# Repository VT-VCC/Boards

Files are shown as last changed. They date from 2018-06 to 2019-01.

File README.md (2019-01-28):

# Board Layouts

This repository contains all of the layouts for the custom boards on the CERES cubesat.

- **Motherboard (Rev. C)** - The current main processor board.
- **Communications Board (Rev. A)** - The current combined PINAV GPS and Lithium Radio commications board.
- **GPS Board** and **Radio Board** - These are legacy designs.

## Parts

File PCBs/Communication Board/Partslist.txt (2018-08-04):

Partlist

Exported from Communication Board Rev A.brd at 8/4/18 3:42 PM

EAGLE Version 9.1.2 Copyright (c) 1988-2018 Autodesk, Inc.

Assembly variant: 

Part            Value                             Package               Library         Position (mil)        Orientation

C1              0.1uF                             C0805                 resistor        (1675 1080)           R270
C2              10uF                              C0805                 resistor        (1670 2615)           R90
C3              0.1uF                             C0805                 resistor        (2386.33858 257.12598) R180
C4              1uF                               C0805                 resistor        (2386.33858 165)      R180
GND             TPSQTP10SQ                        TP10SQ                testpad         (2125 125)            R90
GPS_3V3         TPSQTP10SQ                        TP10SQ                testpad         (1975 125)            R90
GPS_PF          TPSQTP10SQ                        TP10SQ                testpad         (1825 125)            R90
GPS_RX          TPSQTP10SQ                        TP10SQ                testpad         (1375 125)            R90
GPS_TX          TPSQTP10SQ                        TP10SQ                testpad         (1525 125)            R90
GPS_VPP         TPSQTP10SQ                        TP10SQ                testpad         (1675 125)            R90
LITHIUM-2       LI-2                              LI-2                  Cubesat         (275 550)             R0
LI_3V3          TPSQTP10SQ                        TP10SQ                testpad         (775 125)             R90
LI_AMP          TPSQTP10SQ                        TP10SQ                testpad         (625 125)             R90
LI_RST          TPSQTP10SQ                        TP10SQ                testpad         (925 125)             R90
LI_RX           TPSQTP10SQ                        TP10SQ                testpad         (1075 125)            R90
LI_TX           TPSQTP10SQ                        TP10SQ                testpad         (1225 125)            R90
OA_RST          TPSQTP10SQ                        TP10SQ                testpad         (475 125)             R90
PINAV-CONNECTOR HLE-110-02-X-DVHLE-110-X-DV-PE-BA HLE-110-02-X-DV-PE-BE HLE-110-02-X-DV (2421.25984 807.08661) R180
R1              47k                               R0805                 resistor        (875 425)             R0
R2              0                                 R0805                 resistor        (1632 3063)           R270
U$1             PC104_NO_DIMENSION                PC104_NO_DIMENSION    Cubesat         (0 0)                 R0

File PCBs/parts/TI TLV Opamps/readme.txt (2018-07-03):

To import your new library into Eagle:
1. Start Eagle.
2. In the control panel window, Select File -> New -> Library from the menu.
3. In the blank library window, select File -> Execute Script from the menu.
5. Browse to your newly exported Eagle Script file (".scr" file extension)
6. After opening the file, the script will populate the new library.
7. Use File -> Save (or Save As..) to save the library to the desired location in Eagle native format.

**************************************************************
**    !!!!!!!!!!!!!        WARNING        !!!!!!!!!!!!!     **
**************************************************************

Besure to check the documentation layer, "48"/"Document", for important information that may seem to be missing or have not translated properly!

For additional information, please visit this site:
http://www.accelerated-designs.com/help/Eagle_import.html

You may also find this video helpful:
http://youtu.be/5jGuWY-Yy3Q

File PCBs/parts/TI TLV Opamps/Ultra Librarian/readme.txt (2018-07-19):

 

**********************************************************
*************  Important Instructions Follow  ************
**********************************************************
 
All files exported to: D:\Export_Storage\ExportBase\1\3783\Output\Eagle\Eagle\Eagle.xml

To import your new library into Eagle:
1. Start Eagle.
2. In the control panel window, Select File -> New -> Library from the menu.
3. In the blank library window, select File -> Execute Script from the menu.
5. Browse to your newly exported Eagle Script file (".scr" file extension)
6. After opening the file, the script will populate the new library.
7. Use File -> Save (or Save As..) to save the library to the desired location in Eagle native format.

**************************************************************
**    !!!!!!!!!!!!!        WARNING        !!!!!!!!!!!!!     **
**************************************************************

Besure to check the documentation layer, "48"/"Document", for important information that may seem to be missing or have not translated properly!

For additional information, please visit this site:
http://www.accelerated-designs.com/help/Eagle_import.html

You may also find this video helpful:
http://youtu.be/5jGuWY-Yy3Q

Ultra Librarian Gold 8.2.225 Process Report

Message - Padstack "RX66Y20D0T" Shape(4) is a CIRCLE with no diameter.
Message - Padstack "RX90Y24D0T" Shape(4) is a CIRCLE with no diameter.
Message - Padstack "RX78Y22D0T" Shape(4) is a CIRCLE with no diameter.

TextStyle count:  24
Padstack count:   3
Pattern count:    3
Symbol count:     1
Component count:  1

Export

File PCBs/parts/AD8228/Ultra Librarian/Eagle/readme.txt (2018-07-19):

 

**********************************************************
*************  Important Instructions Follow  ************
**********************************************************
 
All files exported to: D:\Export_Storage\ExportBase\1\3786\Output\Eagle\Eagle\Eagle.xml

To import your new library into Eagle:
1. Start Eagle.
2. In the control panel window, Select File -> New -> Library from the menu.
3. In the blank library window, select File -> Execute Script from the menu.
5. Browse to your newly exported Eagle Script file (".scr" file extension)
6. After opening the file, the script will populate the new library.
7. Use File -> Save (or Save As..) to save the library to the desired location in Eagle native format.

**************************************************************
**    !!!!!!!!!!!!!        WARNING        !!!!!!!!!!!!!     **
**************************************************************

Besure to check the documentation layer, "48"/"Document", for important information that may seem to be missing or have not translated properly!

For additional information, please visit this site:
http://www.accelerated-designs.com/help/Eagle_import.html

You may also find this video helpful:
http://youtu.be/5jGuWY-Yy3Q

The Symbol AD8228ARZ was missing a RefDes attribute, a refdes was created for the symbol.
The Symbol AD8228ARZ was missing a Type attribute, a type was created for the symbol.
The Symbol AD8228ARZ was missing a Value attribute, a value was created for the symbol.

Ultra Librarian Gold 8.2.225 Process Report

Message - Padstack "RX74Y20D0T" Shape(4) is a CIRCLE with no diameter.
Message - Padstack "RX98Y24D0T" Shape(4) is a CIRCLE with no diameter.
Message - Padstack "RX86Y22D0T" Shape(4) is a CIRCLE with no diameter.

TextStyle count:  24
Padstack count:   3
Pattern count:    3
Symbol count:     1
Component count:  1

Export

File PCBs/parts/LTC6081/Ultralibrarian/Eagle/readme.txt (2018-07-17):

 

**********************************************************
*************  Important Instructions Follow  ************
**********************************************************
 
All files exported to: D:\Export_Storage\ExportBase\1\3724\Output\Eagle\Eagle\Eagle.xml

To import your new library into Eagle:
1. Start Eagle.
2. In the control panel window, Select File -> New -> Library from the menu.
3. In the blank library window, select File -> Execute Script from the menu.
5. Browse to your newly exported Eagle Script file (".scr" file extension)
6. After opening the file, the script will populate the new library.
7. Use File -> Save (or Save As..) to save the library to the desired location in Eagle native format.

**************************************************************
**    !!!!!!!!!!!!!        WARNING        !!!!!!!!!!!!!     **
**************************************************************

Besure to check the documentation layer, "48"/"Document", for important information that may seem to be missing or have not translated properly!

For additional information, please visit this site:
http://www.accelerated-designs.com/help/Eagle_import.html

You may also find this video helpful:
http://youtu.be/5jGuWY-Yy3Q

Symbol "LTC6081HMS8#PBF" renamed to "LTC6081HMS8PBF"
Component "LTC6081HMS8#PBF" renamed to "LTC6081HMS8PBF"

Ultra Librarian Gold 8.2.225 Process Report

Message - Padstack "RX43Y15D0T" Shape(4) is a CIRCLE with no diameter.
Message - Padstack "RX67Y19D0T" Shape(4) is a CIRCLE with no diameter.
Message - Padstack "RX55Y17D0T" Shape(4) is a CIRCLE with no diameter.

TextStyle count:  24
Padstack count:   3
Pattern count:    3
Symbol count:     1
Component count:  1

Export

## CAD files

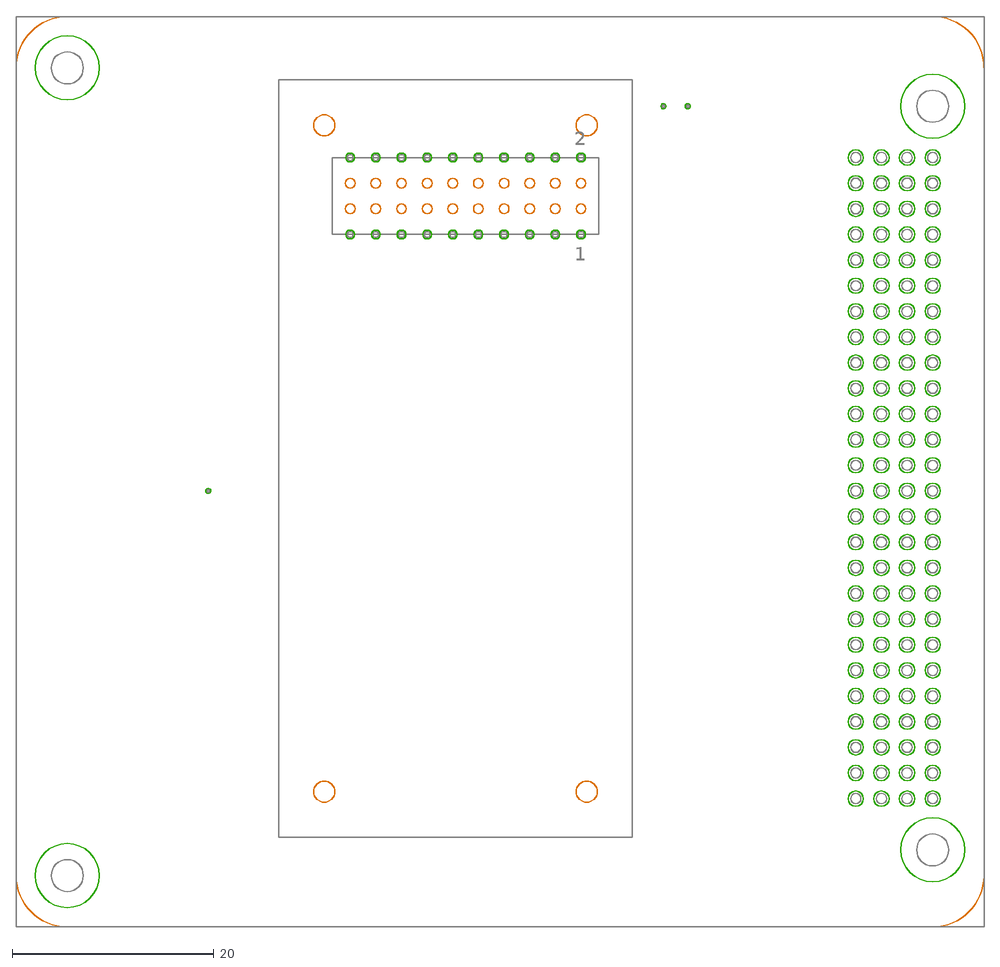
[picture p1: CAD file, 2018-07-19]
PCBs/GPS Board/GPS Board Rev C.dxf
2
1

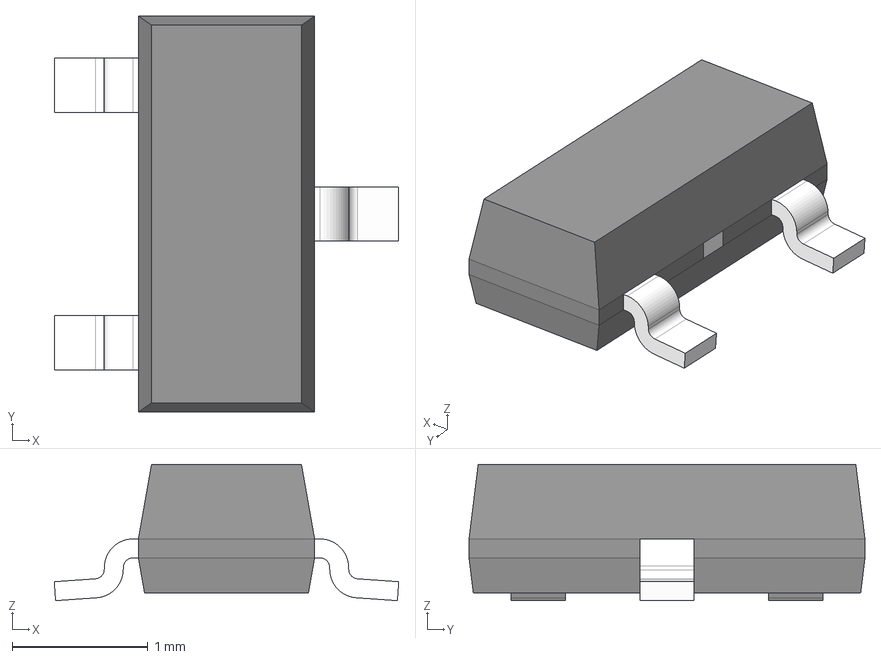
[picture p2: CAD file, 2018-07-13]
PCBs/parts/REF3330/DBZ0003A.stp
2.54 x 2.92 x 1.01 mm
BODY-SOT
LEAD-SOT x 3
PIN1-ID
TIEBAR

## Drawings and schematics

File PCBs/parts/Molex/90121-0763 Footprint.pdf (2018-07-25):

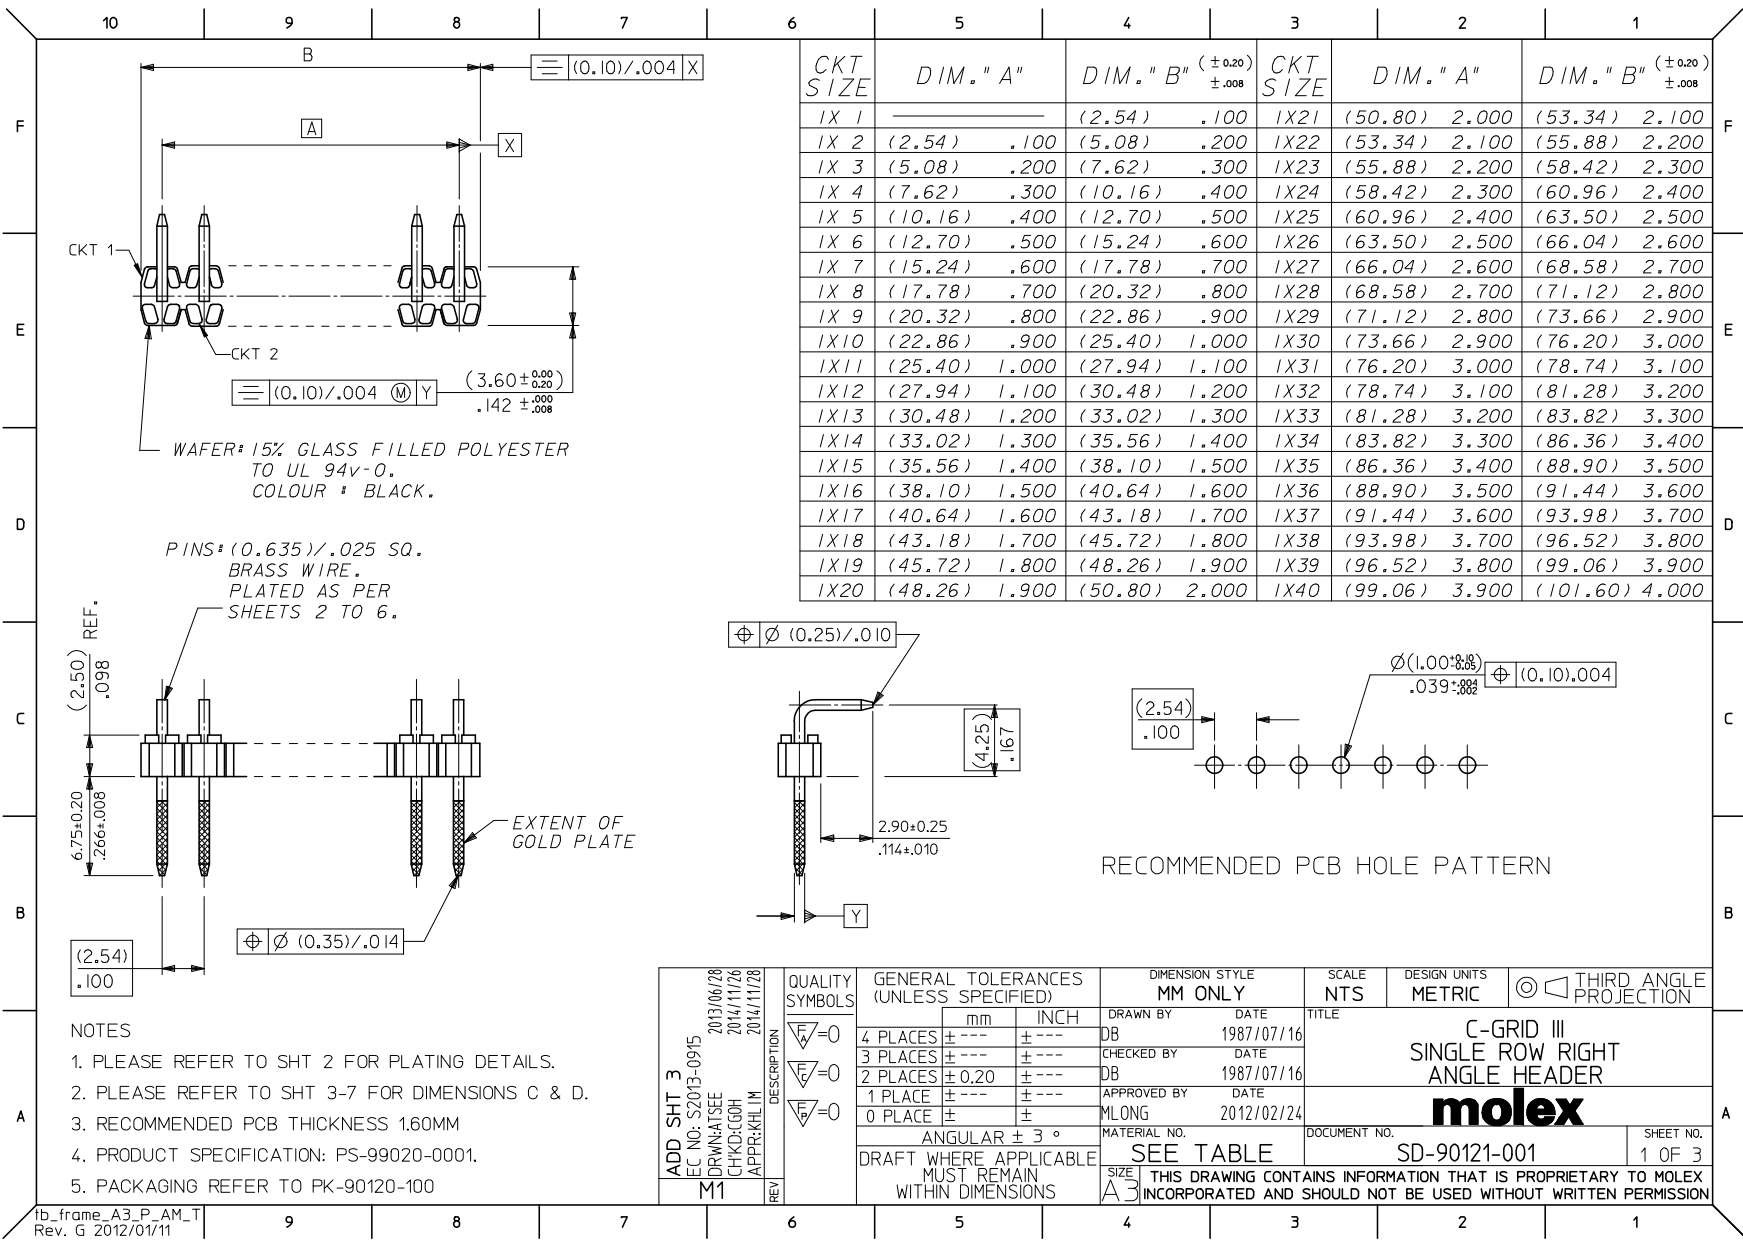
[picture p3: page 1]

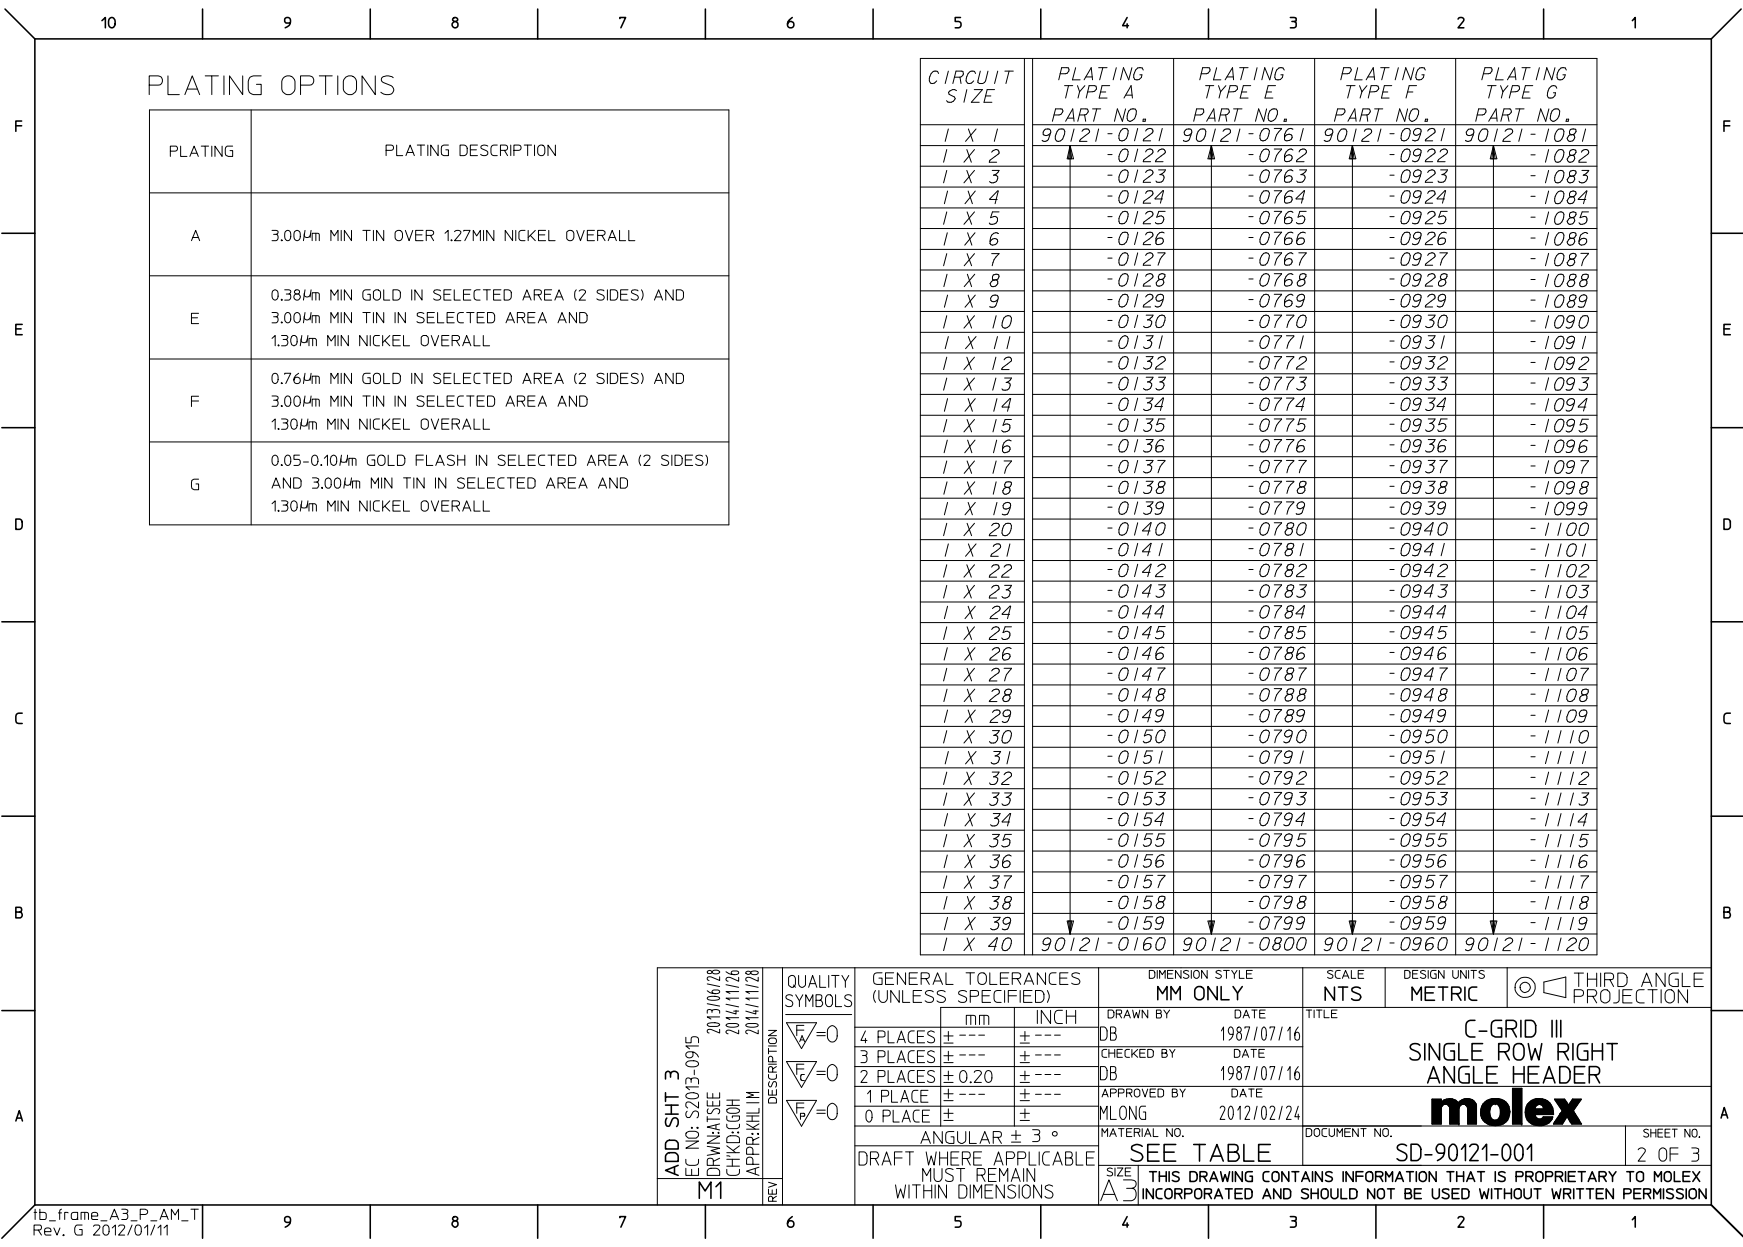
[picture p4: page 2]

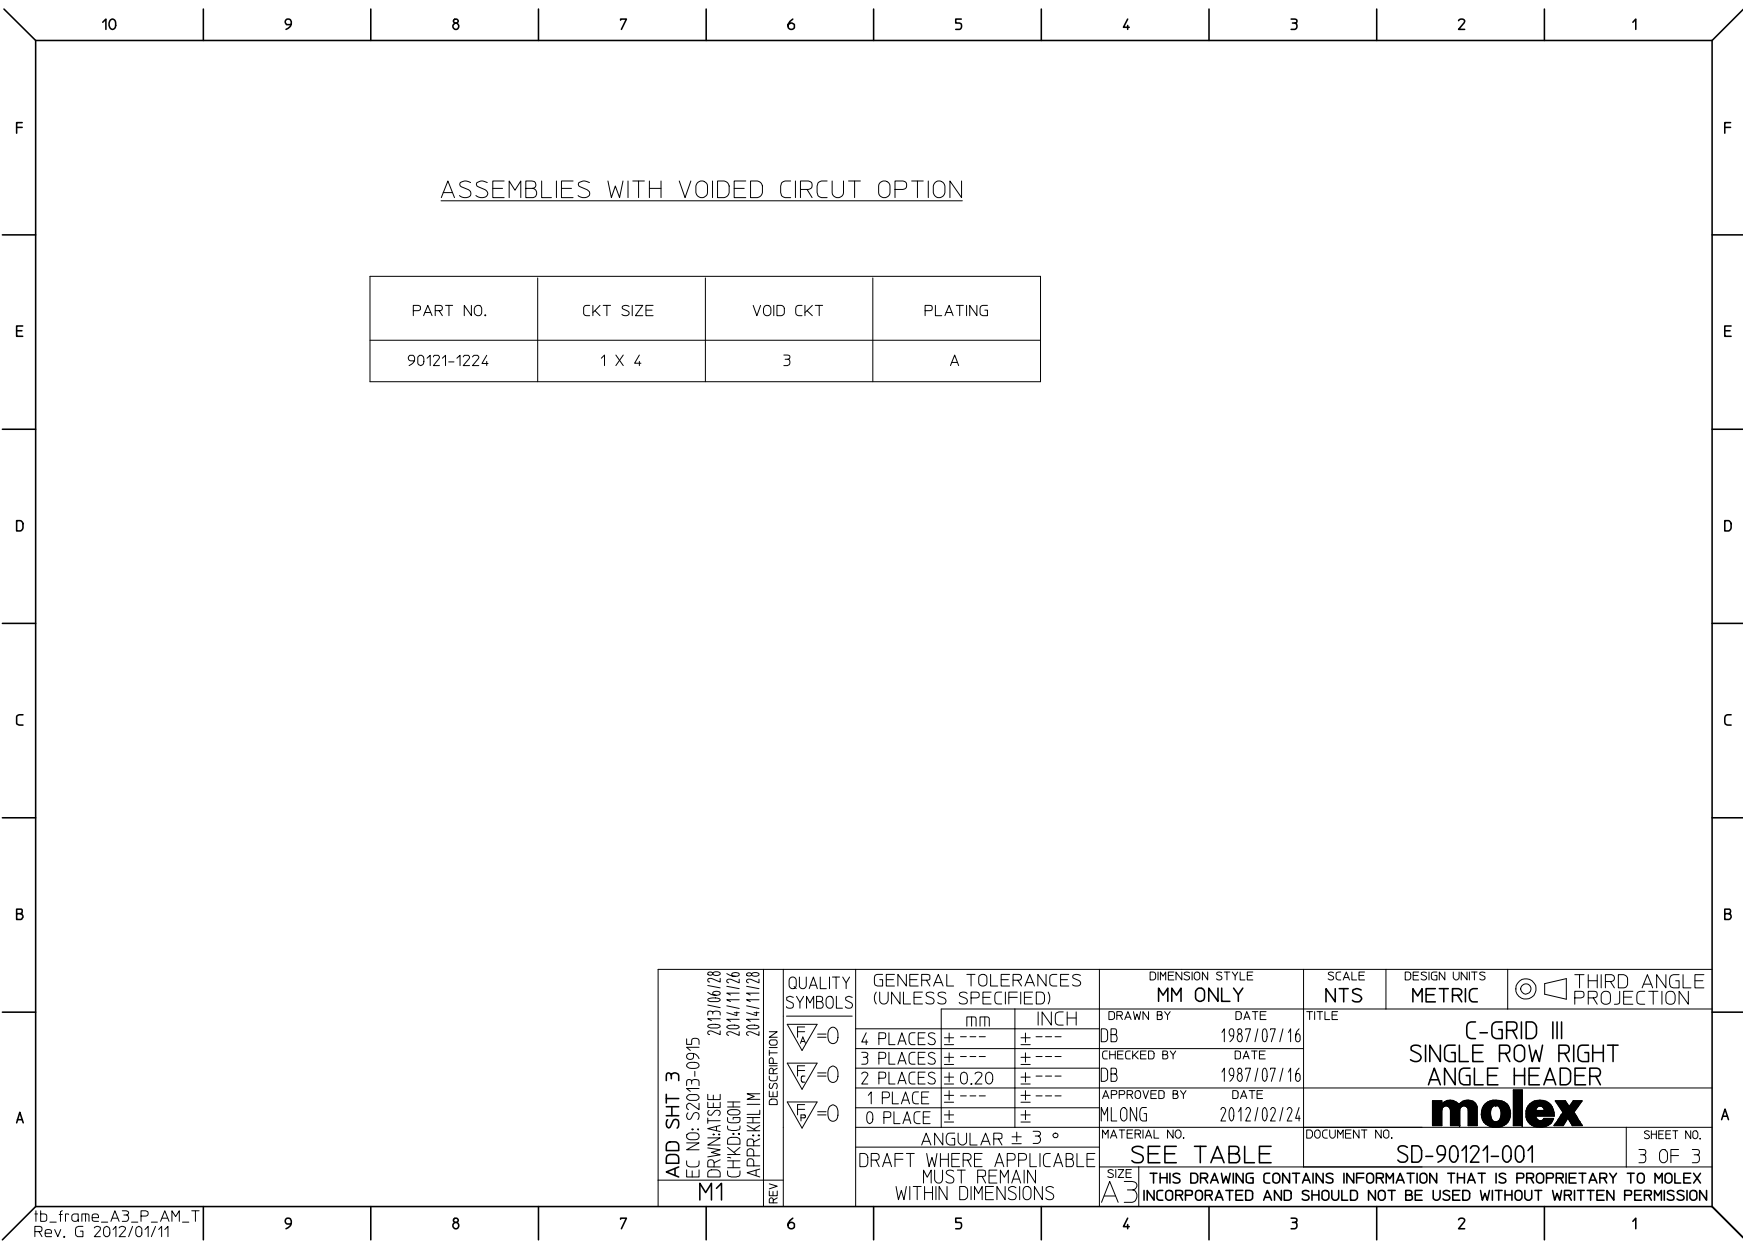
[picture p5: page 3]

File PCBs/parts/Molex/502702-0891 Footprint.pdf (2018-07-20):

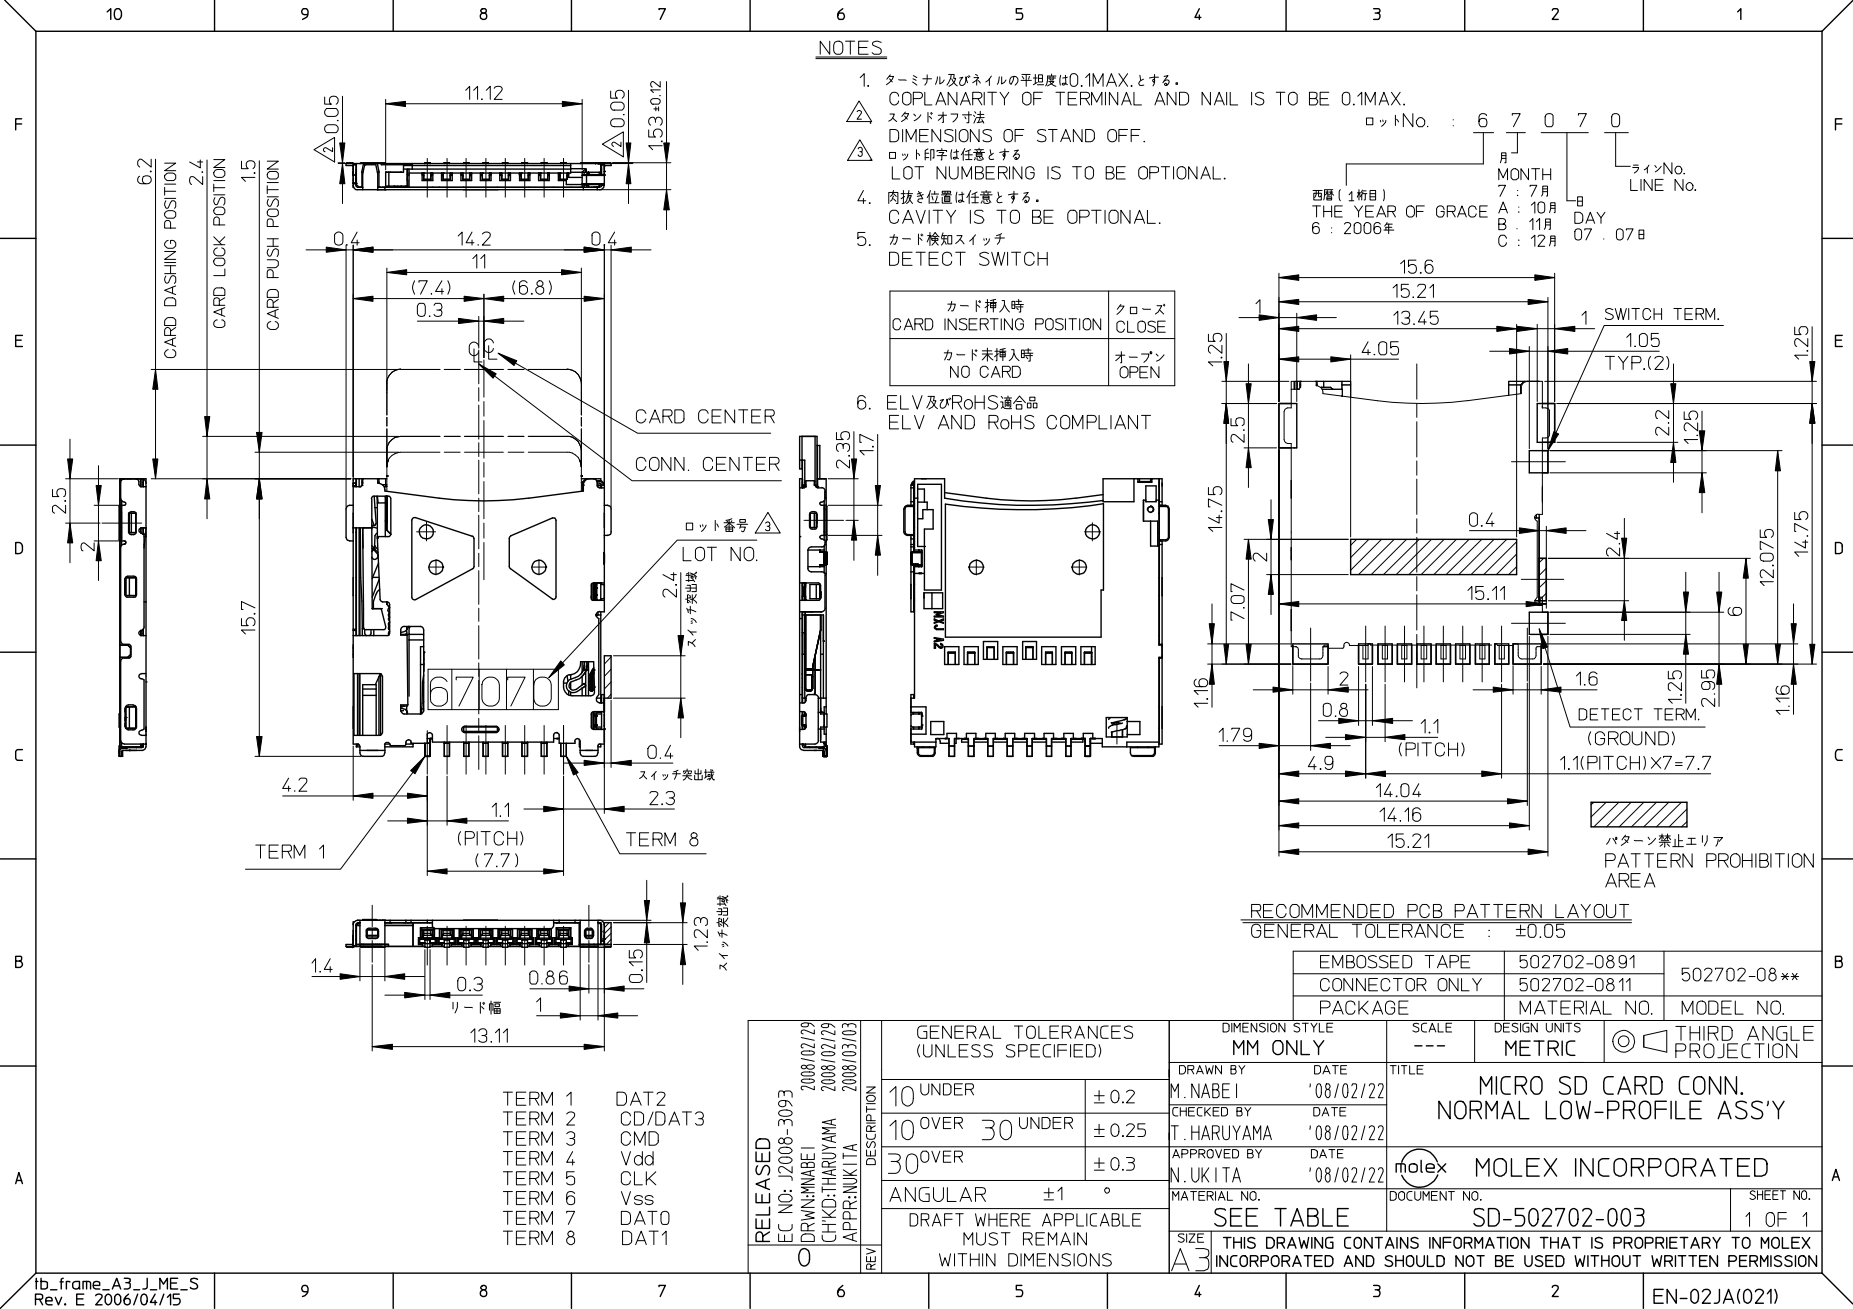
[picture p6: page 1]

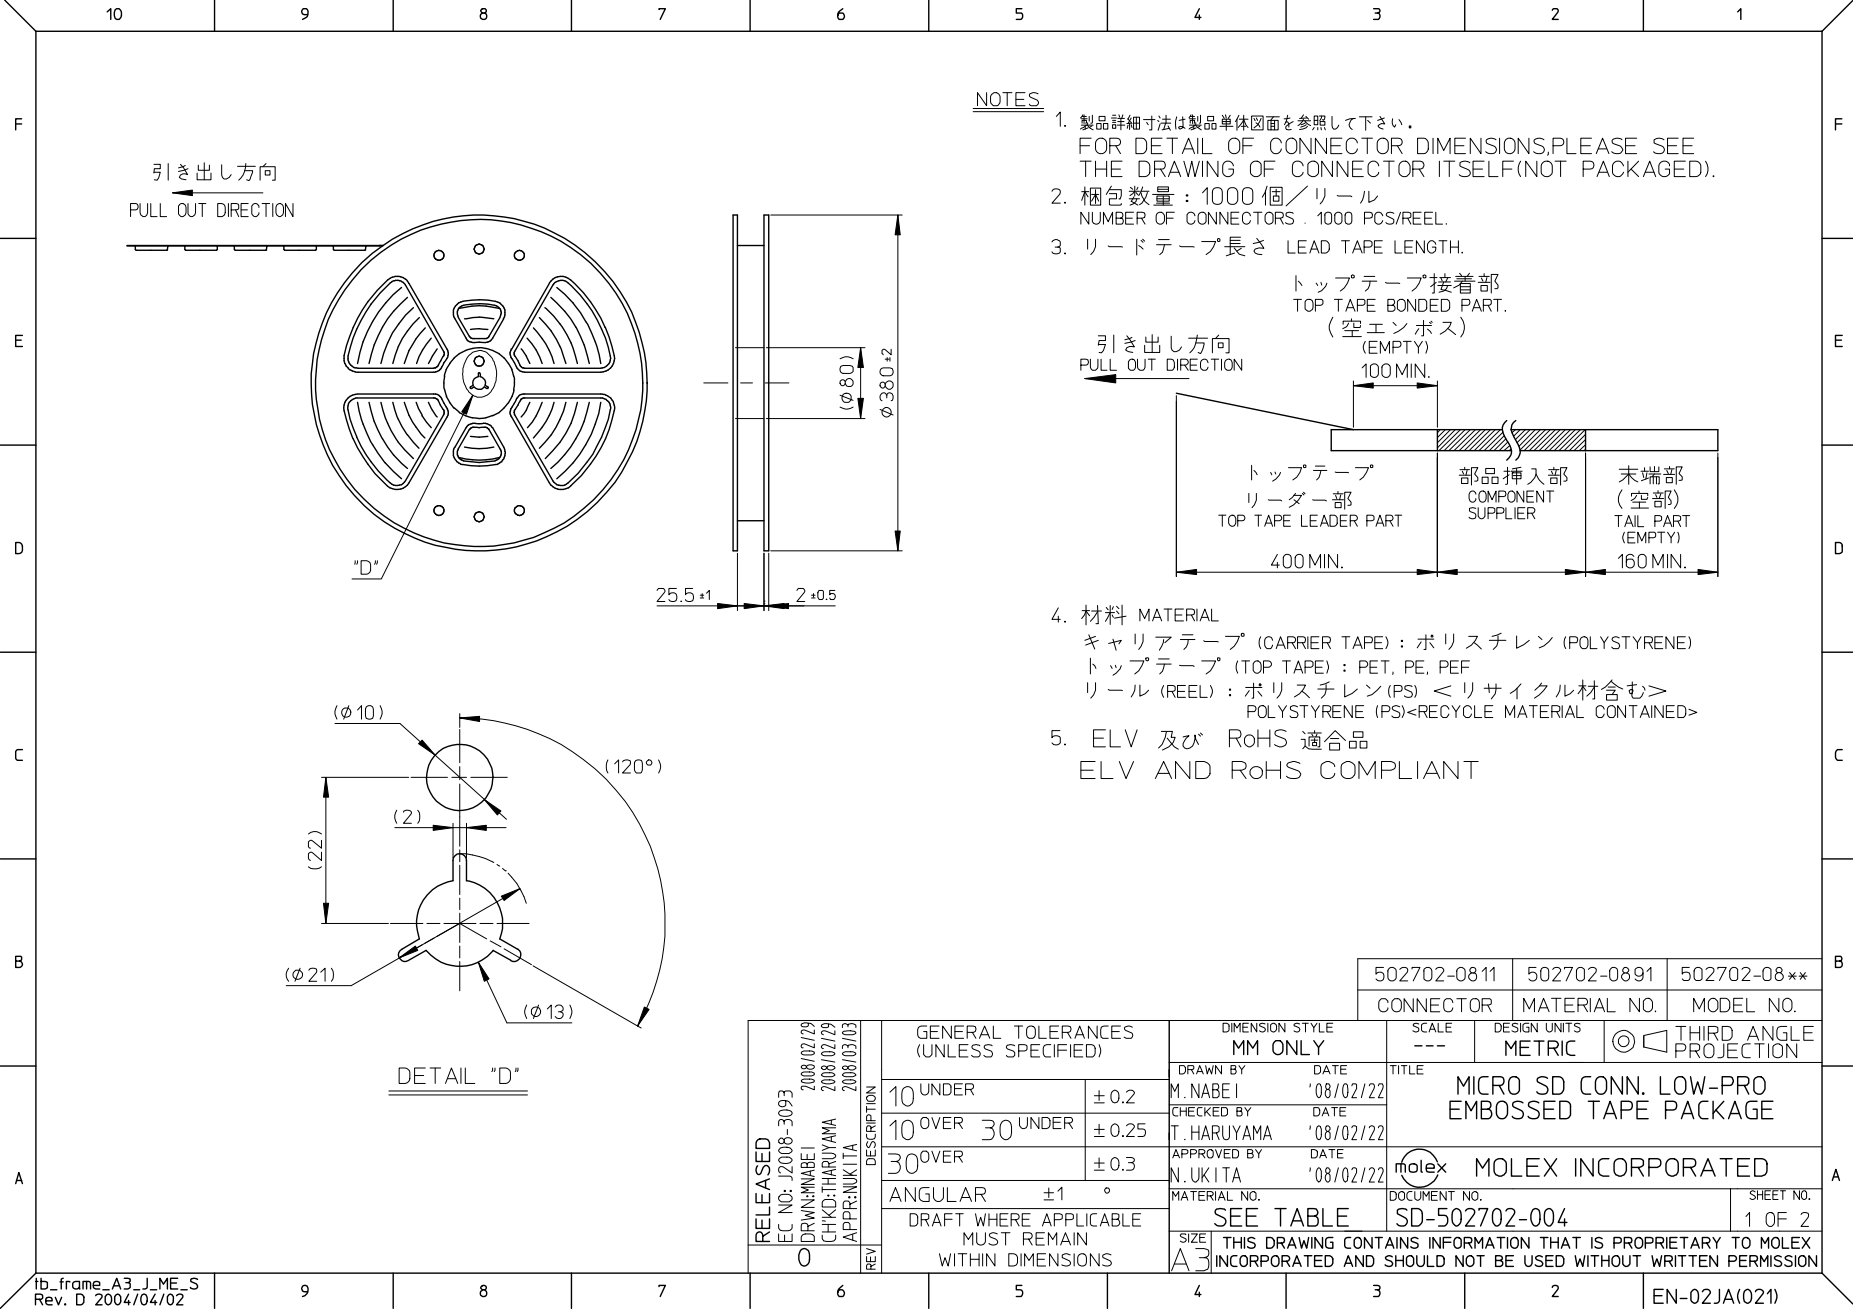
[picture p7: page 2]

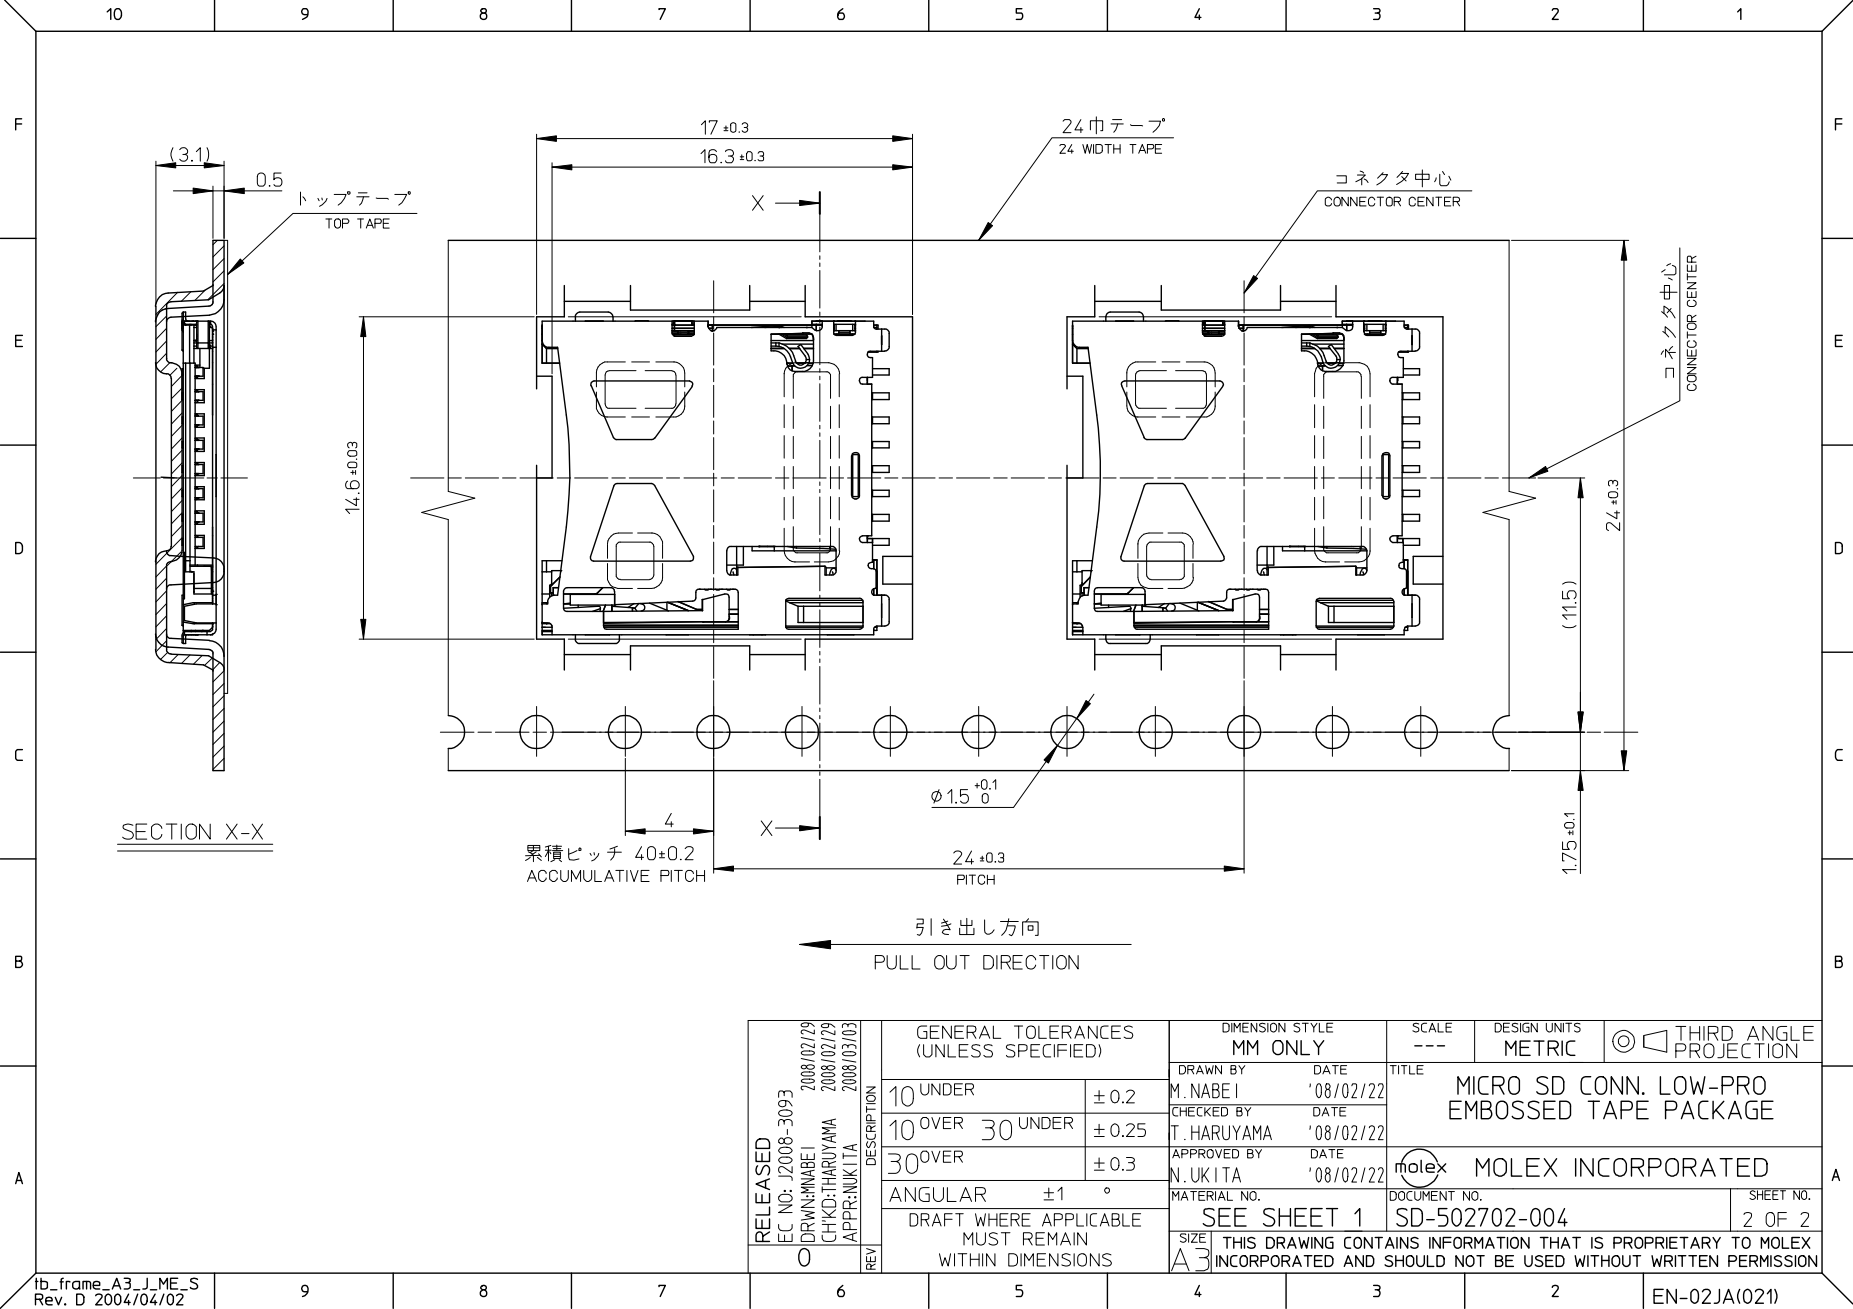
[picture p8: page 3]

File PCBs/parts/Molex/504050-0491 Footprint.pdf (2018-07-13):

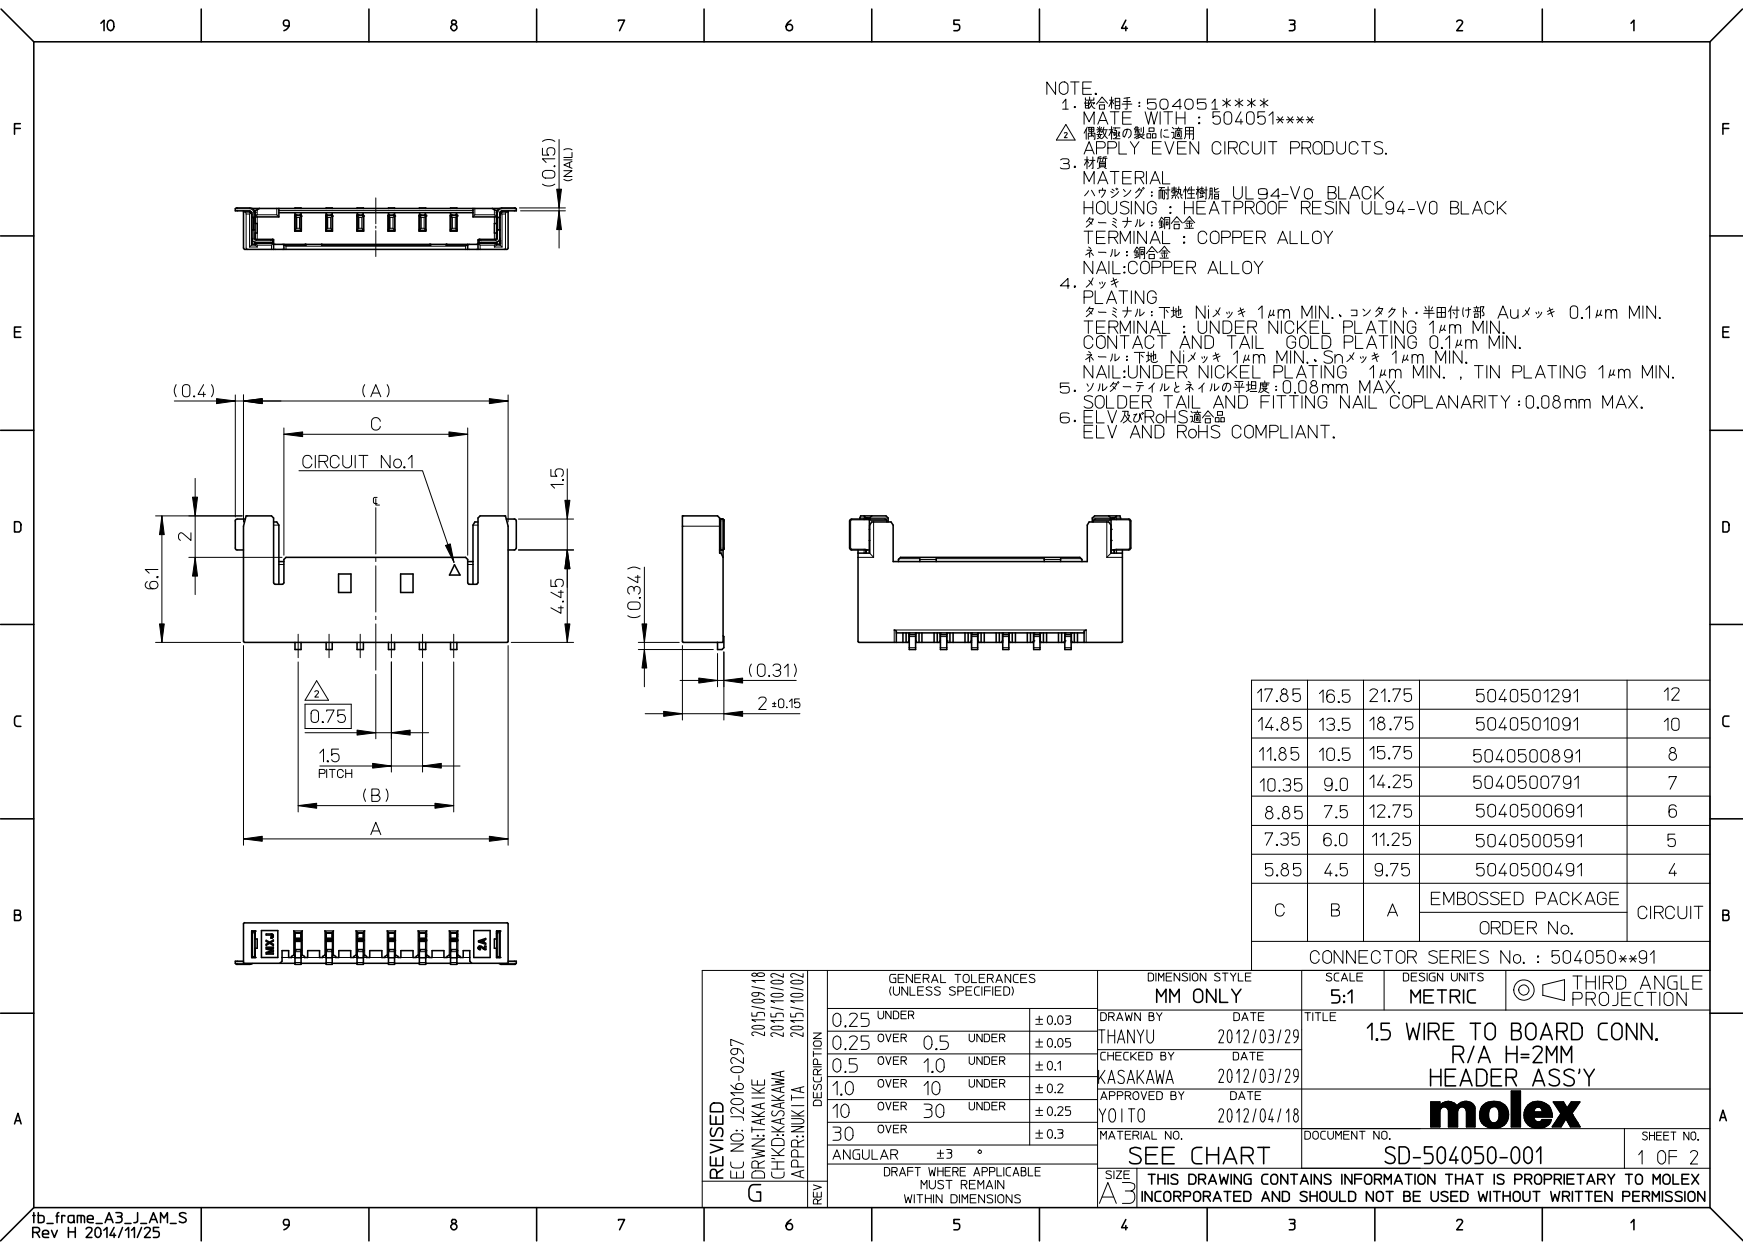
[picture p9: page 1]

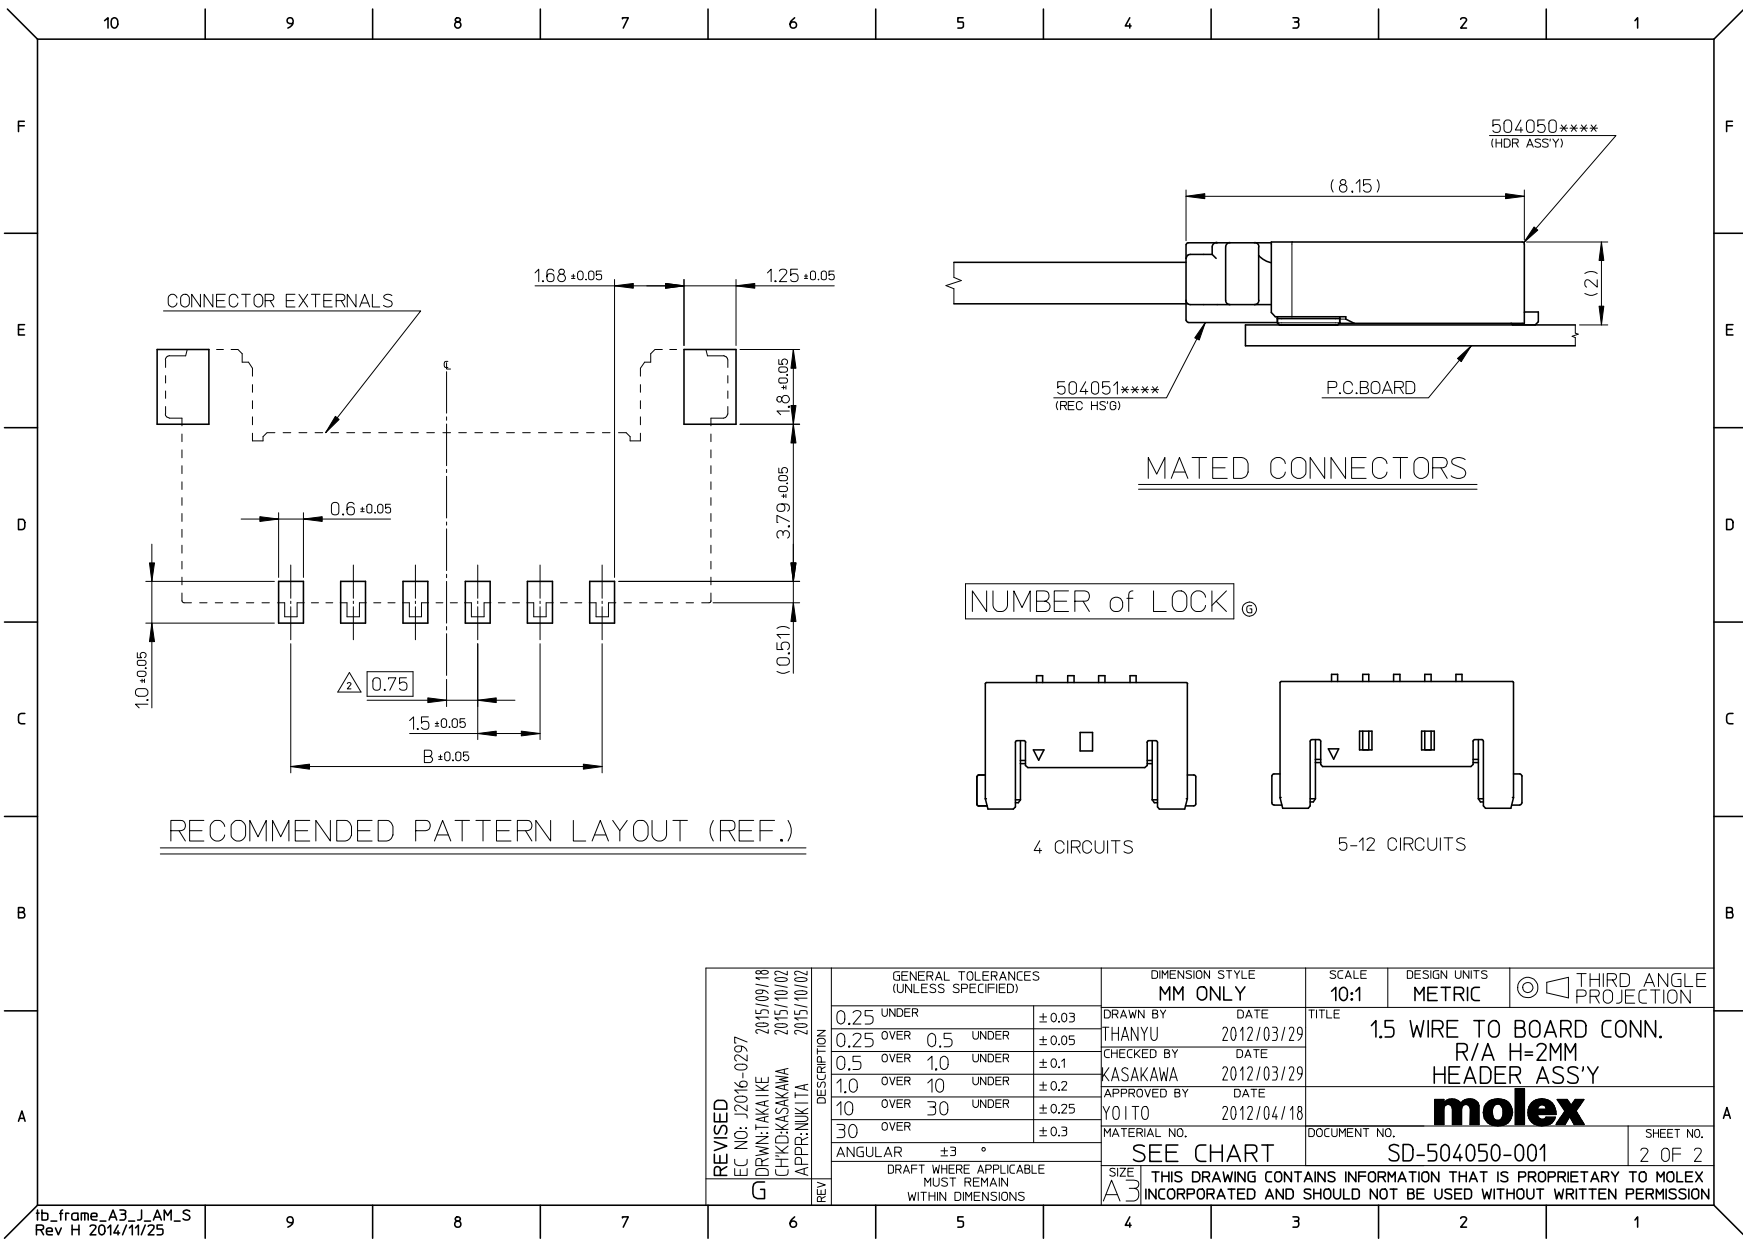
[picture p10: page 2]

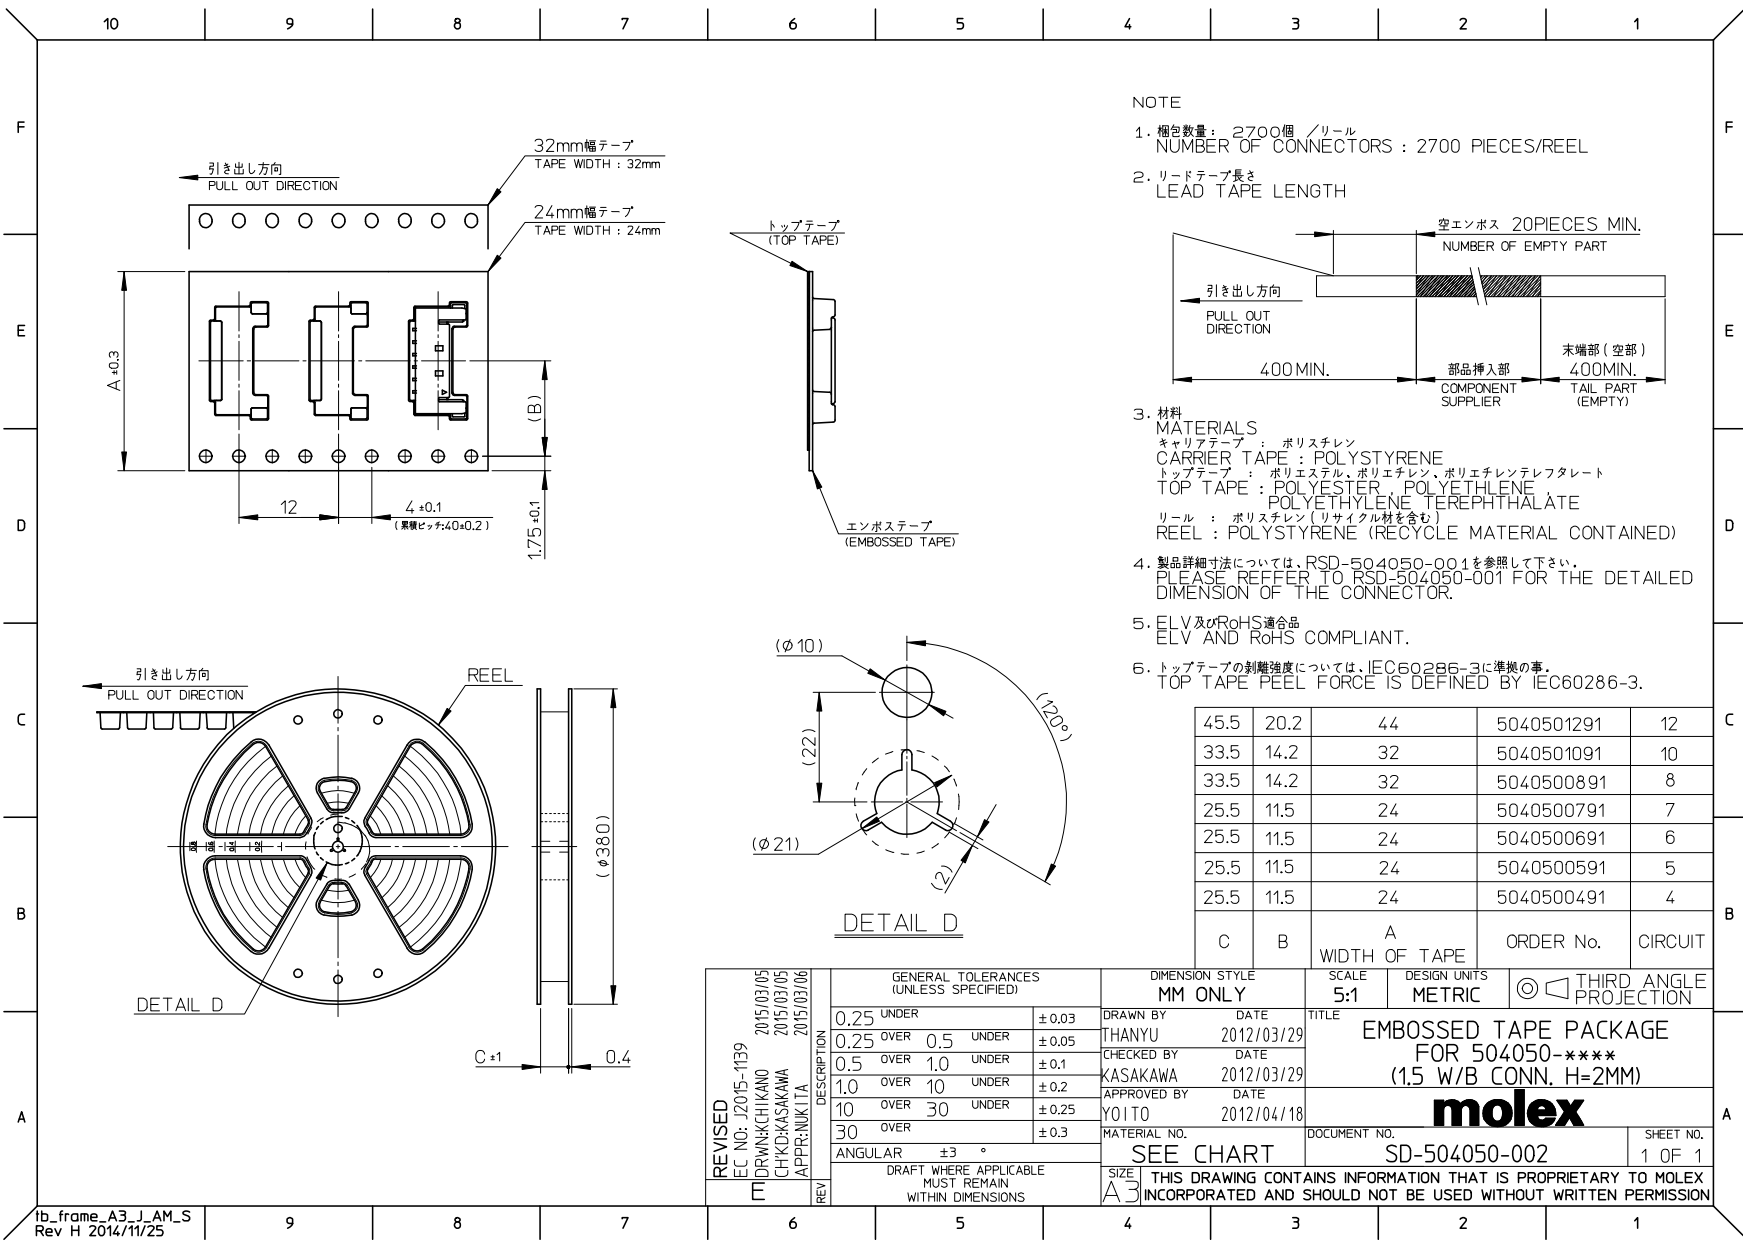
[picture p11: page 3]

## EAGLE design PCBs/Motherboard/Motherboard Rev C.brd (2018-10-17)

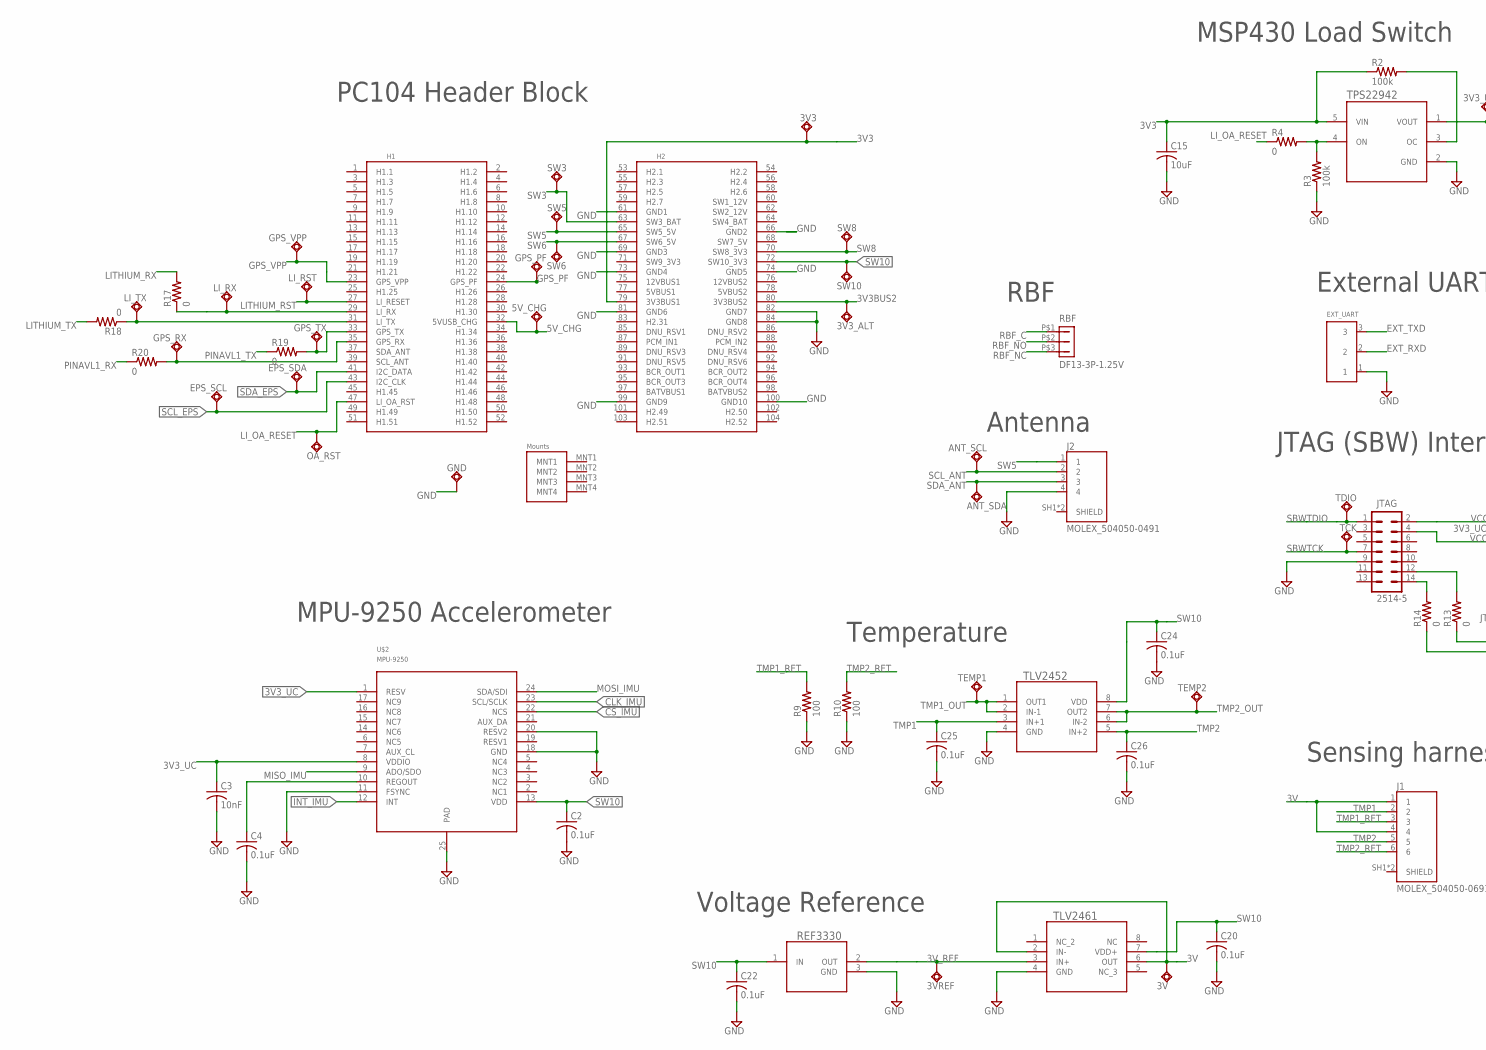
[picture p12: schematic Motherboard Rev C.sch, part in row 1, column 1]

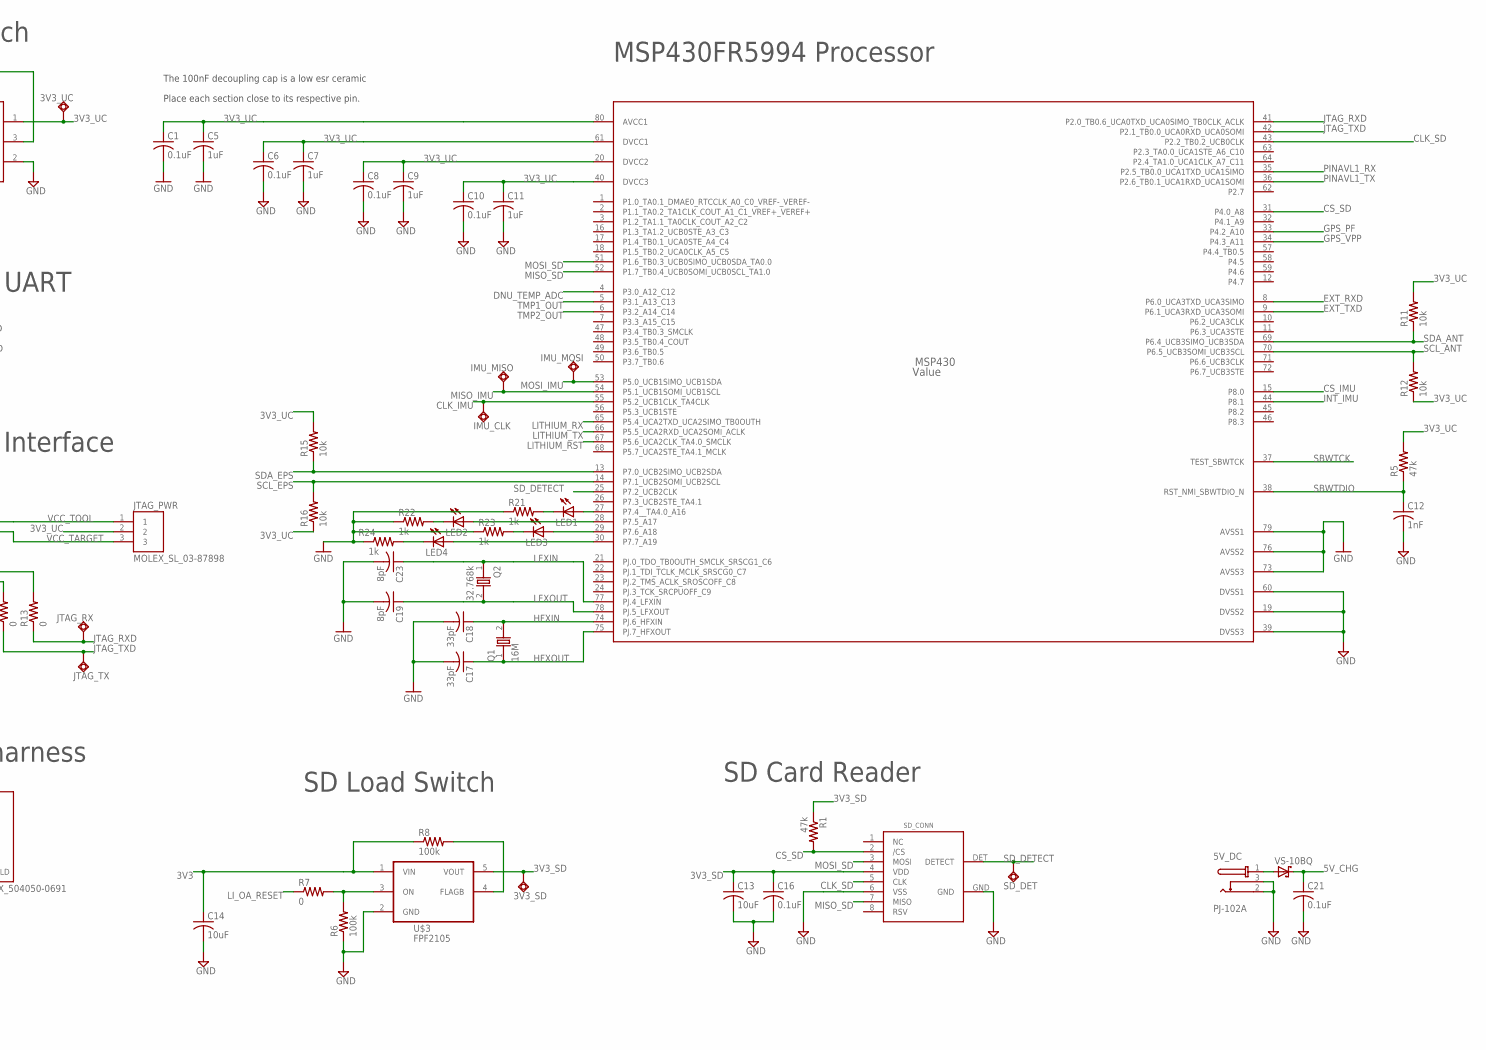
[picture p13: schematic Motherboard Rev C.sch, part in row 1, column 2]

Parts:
3V, 3V3, 3V3_ALT, 3V3_SD, 3V3_UC, 3VREF, 5V_CHG: TPSQTP10SQ; TP10SQ
5V_DC: PJ-102A; CUI_PJ-102A
ANT_SCL: TPSQTP10SQ; TP10SQ
ANT_SDA: TPSQTP10SQ; TP10SQ
C1, C2, C4, C6, C8, C10, C16, C20, C21, C22, C24, C25, C26: 0.1uF; C0805
C3: 10nF; C0805
C5, C7, C9, C11: 1uF; C0805
C12: 1nF; C0805
C13, C14, C15: 10uF; C0805
C17, C18: 33pF; C0805
C19, C23: 8pF; C0805
EPS_SCL: TPSQTP10SQ; TP10SQ
EPS_SDA: TPSQTP10SQ; TP10SQ
EXT_UART: 90121-0763
GND: TPSQTP10SQ; TP10SQ
GPS_PF: TPSQTP10SQ; TP10SQ
GPS_RX: TPSQTP10SQ; TP10SQ
GPS_TX: TPSQTP10SQ; TP10SQ
GPS_VPP: TPSQTP10SQ; TP10SQ
IMU_CLK: TPSQTP06SQ; TP06SQ
IMU_MISO: TPSQTP06SQ; TP06SQ
IMU_MOSI: TPSQTP06SQ; TP06SQ
J1: MOLEX_504050-0691; MOLEX_5040500691
J2: MOLEX_504050-0491; MOLEX_5040500491
JTAG: 2514-5; PAK100/2500-5-14
JTAG_PWR: MOLEX_SL_03-87898; SL_87898_3
JTAG_RX: TPSQTP10SQ; TP10SQ
JTAG_TX: TPSQTP10SQ; TP10SQ
LED1, LED2, LED3, LED4: LEDSML0805; SML0805
LI_RST: TPSQTP10SQ; TP10SQ
LI_RX: TPSQTP10SQ; TP10SQ
LI_TX: TPSQTP10SQ; TP10SQ
MSP430: Value; PN0080A_N
OA_RST: TPSQTP10SQ; TP10SQ
Q1: 16M; 5X3.2
Q2: 32.768k; MS1V-T1K
R1, R5: 47k; R0805
R2, R3, R6, R8: 100k; R0805
R4, R7, R13, R14, R17, R18, R19, R20: 0; R0805
R9, R10: 100; R0805
R11, R12, R15, R16: 10k; R0805
R21, R22, R23, R24: 1k; R0805
RBF: DF13-3P-1.25V; DF13C-3P-1.25V
REF3330: REF3330_DBZ_3; DBZ3
SD_CONN: 502702-0891; 502702
SD_DET: TPSQTP10SQ; TP10SQ
SW3, SW5, SW6, SW8, SW10: TPSQTP10SQ; TP10SQ
TCK: TPSQTP10SQ; TP10SQ
TDIO: TPSQTP10SQ; TP10SQ
TEMP1, TEMP2: TPSQTP10SQ; TP10SQ
TLV2452: TLV2452; D8
TLV2461: TLV2461A_D_8; D8
TPS22942: TPS22942DCKR; DCK0005A
U$1: PC104_NO_DIMENSION
U$2: MPU-9250; LEAD-QFN24
U$3: FPF2105; SOT23-5
VS-10BQ: 10BQ015HM3; SMB

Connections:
3V: 3V.TP, J1.1, J1.4, TLV2461.2 (IN-), TLV2461.6 (OUT)
3V3: 3V3.TP, C14.1, C15.1, R2.1, R8.1, TPS22942.5 (VIN), U$1.79 (3V3BUS1), U$3.1 (VIN)
3V3BUS2: 3V3_ALT.TP, U$1.80 (3V3BUS2)
3V3_SD: 3V3_SD.TP, C13.1, C16.1, R1.1, SD_CONN.4 (VDD), U$3.5 (VOUT)
3V3_UC: 3V3_UC.TP, C1.1, C3.1, C5.1, C6.1, C7.1, C8.1, C9.1, C10.1, C11.1, JTAG_PWR.2, MSP430.20 (DVCC2), MSP430.40 (DVCC3), MSP430.61 (DVCC1), MSP430.80 (AVCC1), R5.2, R11.2, R12.1, R15.2, R16.1, TPS22942.1 (VOUT), U$2.1 (RESV), U$2.8 (VDDIO)
3V_REF: 3VREF.TP, REF3330.2 (OUT), TLV2461.3 (IN+)
5V_CHG: 5V_CHG.TP, C21.1, U$1.32 (5VUSB_CHG), VS-10BQ.C
CLK_IMU: IMU_CLK.TP, MSP430.55 (P5.2_UCB1CLK_TA4CLK), U$2.23 (SCL/SCLK)
CLK_SD: MSP430.43 (P2.2_TB0.2_UCB0CLK), SD_CONN.5 (CLK)
CS_IMU: MSP430.15 (P8.0), U$2.22 (NCS)
CS_SD: MSP430.31 (P4.0_A8), R1.2, SD_CONN.2 (/CS)
DNU_TEMP_ADC: MSP430.4 (P3.0_A12_C12)
EXT_RXD: EXT_UART.2, MSP430.8 (P6.0_UCA3TXD_UCA3SIMO)
EXT_TXD: EXT_UART.3, MSP430.9 (P6.1_UCA3RXD_UCA3SOMI)
GND: 5V_DC.2, 5V_DC.3, C1.2, C2.2, C3.2, C4.2, C5.2, C6.2, C7.2, C8.2, C9.2, C10.2, C11.2, C12.2, C13.2, C14.2, C15.2, C16.2, C17.2, C18.2, C19.2, C20.2, C21.2, C22.2, C23.2, C24.2, C25.2, C26.2, EXT_UART.1, GND.TP, J2.4, JTAG.9, MSP430.19 (DVSS2), MSP430.39 (DVSS3), MSP430.60 (DVSS1), MSP430.73 (AVSS3), MSP430.76 (AVSS2), MSP430.79 (AVSS1), R3.1, R6.1, R9.1, R10.1, R21.1, R22.1, R23.1, R24.1, REF3330.3 (GND), SD_CONN.6 (VSS), SD_CONN.GND, TLV2452.4 (GND), TLV2461.4 (GND), TPS22942.2 (GND), U$1.61 (GND1), U$1.66 (GND2), U$1.69 (GND3), U$1.73 (GND4), U$1.74 (GND5), U$1.81 (GND6), U$1.82 (GND7), U$1.84 (GND8), U$1.99 (GND9), U$1.100 (GND10), U$2.11 (FSYNC), U$2.18 (GND), U$2.20 (RESV2), U$2.25 (PAD), U$3.2 (GND)
GPS_PF: GPS_PF.TP, MSP430.33 (P4.2_A10), U$1.24 (GPS_PF)
GPS_VPP: GPS_VPP.TP, MSP430.34 (P4.3_A11), U$1.23 (GPS_VPP)
HFXIN: C18.1, MSP430.74 (PJ.6_HFXIN), Q1.2
HFXOUT: C17.1, MSP430.75 (PJ.7_HFXOUT), Q1.1
INT_IMU: MSP430.44 (P8.1), U$2.12 (INT)
JTAG_RXD: JTAG_RX.TP, MSP430.41 (P2.0_TB0.6_UCA0TXD_UCA0SIMO_TB0CLK_ACLK), R13.1
JTAG_TXD: JTAG_TX.TP, MSP430.42 (P2.1_TB0.0_UCA0RXD_UCA0SOMI), R14.1
LFXIN: C23.1, MSP430.77 (PJ.4_LFXIN), Q2.1
LFXOUT: C19.1, MSP430.78 (PJ.5_LFXOUT), Q2.2
LITHIUM_RST: LI_RST.TP, MSP430.67 (P5.6_UCA2CLK_TA4.0_SMCLK), U$1.27 (LI_RESET)
LITHIUM_RX: MSP430.65 (P5.4_UCA2TXD_UCA2SIMO_TB0OUTH), R17.2
LITHIUM_TX: MSP430.66 (P5.5_UCA2RXD_UCA2SOMI_ACLK), R18.2
LI_OA_RESET: OA_RST.TP, R4.1, R7.1, U$1.47 (LI_OA_RST)
MISO_IMU: IMU_MISO.TP, MSP430.54 (P5.1_UCB1SOMI_UCB1SCL), U$2.9 (ADO/SDO)
MISO_SD: MSP430.52 (P1.7_TB0.4_UCB0SOMI_UCB0SCL_TA1.0), SD_CONN.7 (MISO)
MOSI_IMU: IMU_MOSI.TP, MSP430.53 (P5.0_UCB1SIMO_UCB1SDA), U$2.24 (SDA/SDI)
MOSI_SD: MSP430.51 (P1.6_TB0.3_UCB0SIMO_UCB0SDA_TA0.0), SD_CONN.3 (MOSI)
unnamed: R2.2, TPS22942.3 (OC)
unnamed: R6.2, R7.2, U$3.3 (ON)
unnamed: C4.1, U$2.10 (REGOUT)
unnamed: LED1.C, R21.2
unnamed: R3.2, R4.2, TPS22942.4 (ON)
unnamed: LED1.A, MSP430.27 (P7.4__TA4.0_A16)
unnamed: R8.2, U$3.4 (FLAGB)
unnamed: JTAG.14, R14.2
unnamed: LED2.A, MSP430.28 (P7.5_A17)
unnamed: LED2.C, R22.2
unnamed: JTAG.12, R13.2
unnamed: LED3.A, MSP430.29 (P7.6_A18)
unnamed: 5V_DC.1, VS-10BQ.A
unnamed: LED3.C, R23.2
unnamed: LED4.A, MSP430.30 (P7.7_A19)
unnamed: LED4.C, R24.2
unnamed: GPS_RX.TP, R20.2, U$1.35 (GPS_RX)
unnamed: GPS_TX.TP, R19.2, U$1.33 (GPS_TX)
unnamed: LI_TX.TP, R18.1, U$1.31 (LI_TX)
unnamed: LI_RX.TP, R17.1, U$1.29 (LI_RX)
PINAVL1_RX: MSP430.35 (P2.5_TB0.0_UCA1TXD_UCA1SIMO), R20.1
PINAVL1_TX: MSP430.36 (P2.6_TB0.1_UCA1RXD_UCA1SOMI), R19.1
RBF_C: RBF.P$1 (1)
RBF_NC: RBF.P$3 (3)
RBF_NO: RBF.P$2 (2)
SBWTCK: JTAG.7, MSP430.37 (TEST_SBWTCK), TCK.TP
SBWTDIO: C12.1, JTAG.1, MSP430.38 (RST_NMI_SBWTDIO_N), R5.1, TDIO.TP
SCL_ANT: ANT_SCL.TP, J2.2, MSP430.70 (P6.5_UCB3SOMI_UCB3SCL), R12.2
SCL_EPS: EPS_SCL.TP, MSP430.14 (P7.1_UCB2SOMI_UCB2SCL), R16.2, U$1.43 (I2C_CLK)
SDA_ANT: ANT_SDA.TP, J2.3, MSP430.69 (P6.4_UCB3SIMO_UCB3SDA), R11.1
SDA_EPS: EPS_SDA.TP, MSP430.13 (P7.0_UCB2SIMO_UCB2SDA), R15.1, U$1.41 (I2C_DATA)
SD_DETECT: MSP430.25 (P7.2_UCB2CLK), SD_CONN.DET (DETECT), SD_DET.TP
SHIELD: J1.SH1 (SHIELD), J1.SH2 (SHIELD), J2.SH1 (SHIELD), J2.SH2 (SHIELD)
SW3: SW3.TP, U$1.63 (SW3_BAT)
SW5: J2.1, SW5.TP, U$1.65 (SW5_5V)
SW6: SW6.TP, U$1.67 (SW6_5V)
SW8: SW8.TP, U$1.70 (SW8_3V3)
SW10: C2.1, C20.1, C22.1, C24.1, REF3330.1 (IN), SW10.TP, TLV2452.8 (VDD), TLV2461.7 (VDD+), U$1.72 (SW10_3V3), U$2.13 (VDD)
TMP1: C25.1, J1.2, TLV2452.3 (IN+1)
TMP1_OUT: MSP430.5 (P3.1_A13_C13), TEMP1.TP, TLV2452.1 (OUT1), TLV2452.2 (IN-1)
TMP1_RET: J1.3, R9.2
TMP2: C26.1, J1.5, TLV2452.5 (IN+2)
TMP2_OUT: MSP430.6 (P3.2_A14_C14), TEMP2.TP, TLV2452.6 (IN-2), TLV2452.7 (OUT2)
TMP2_RET: J1.6, R10.2
VCC_TARGET: JTAG.4, JTAG_PWR.3
VCC_TOOL: JTAG.2, JTAG_PWR.1

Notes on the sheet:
MPU-9250 Accelerometer
MSP430FR5994 Processor
PC104 Header Block
The 100nF decoupling cap is a low esr ceramic
Place each section close to its respective pin.
SD Card Reader
JTAG (SBW) Interface
Sensing harness
MSP430 Load Switch
SD Load Switch
Temperature
Voltage Reference
Antenna
External UART
RBF

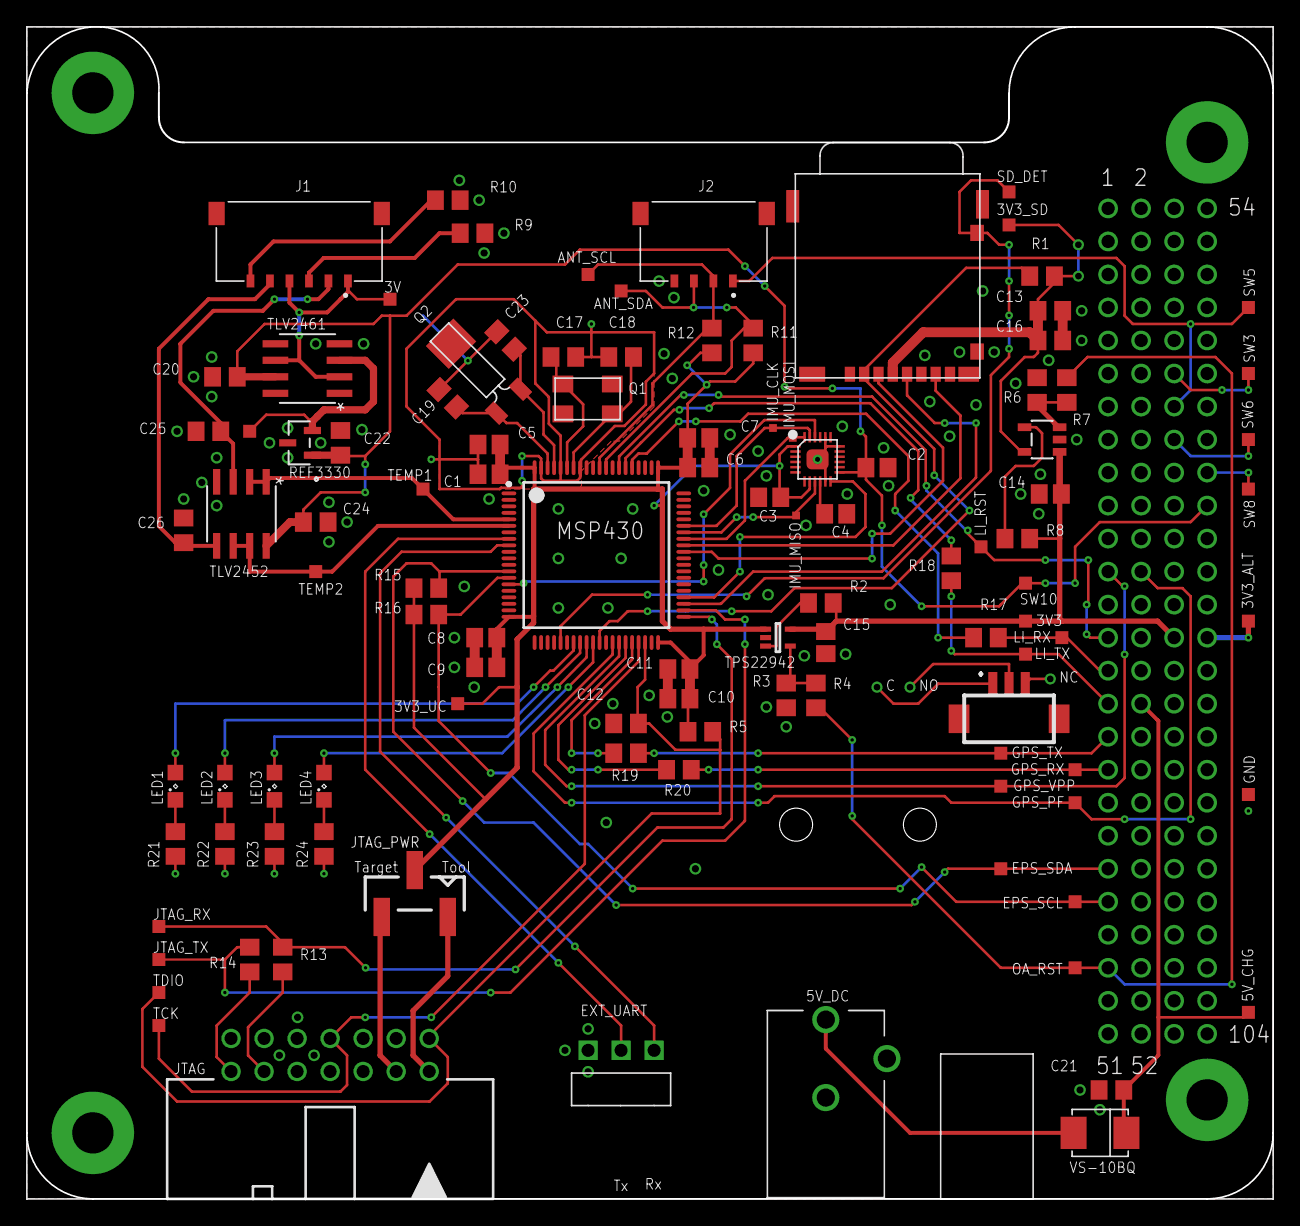
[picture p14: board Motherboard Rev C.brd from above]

Board: 2 copper layers, 95.9 x 90.2 mm, 109 parts (0 on the bottom side), 74 nets.

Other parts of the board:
U$4: RBF_MOUNT

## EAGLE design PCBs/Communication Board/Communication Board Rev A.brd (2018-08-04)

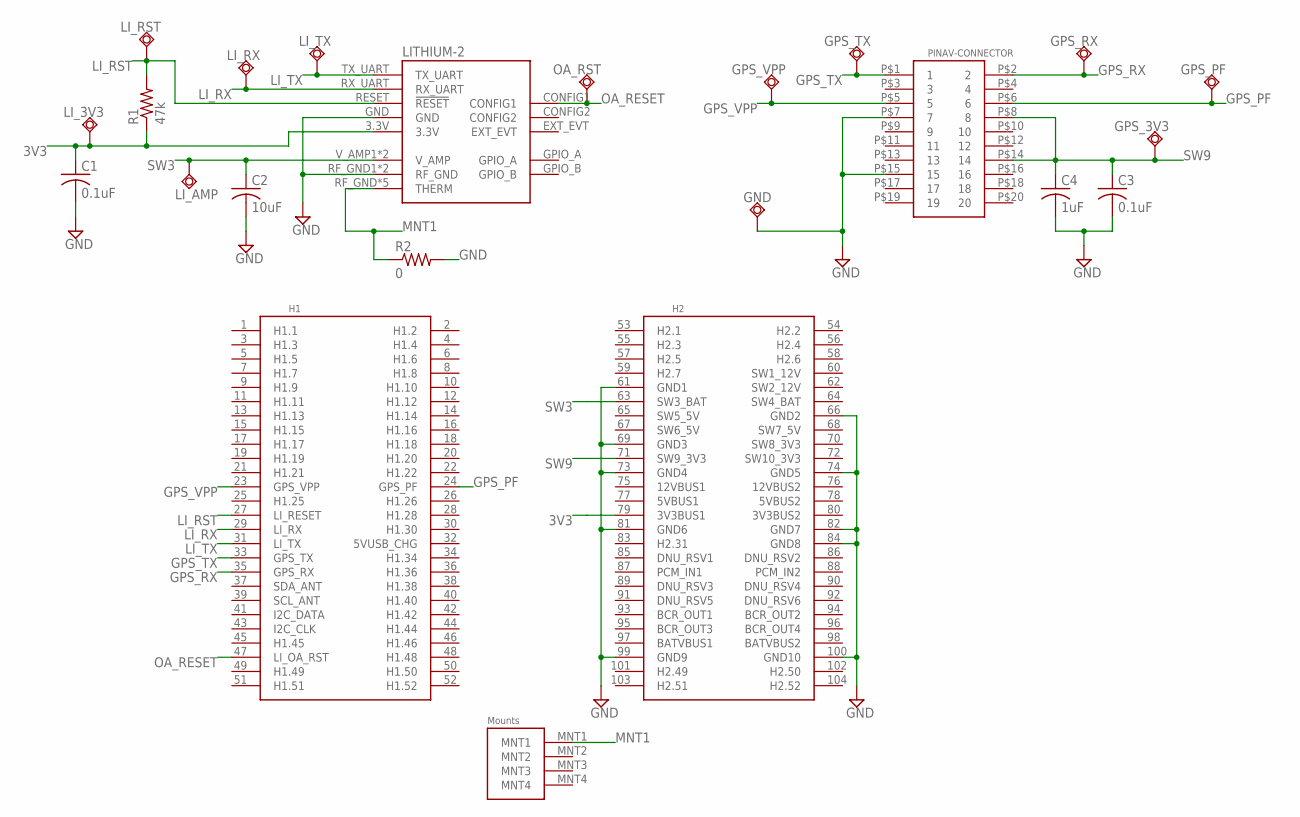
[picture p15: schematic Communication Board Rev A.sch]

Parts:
C1, C3: 0.1uF; C0805
C2: 10uF; C0805
C4: 1uF; C0805
GND: TPSQTP10SQ; TP10SQ
GPS_3V3: TPSQTP10SQ; TP10SQ
GPS_PF: TPSQTP10SQ; TP10SQ
GPS_RX: TPSQTP10SQ; TP10SQ
GPS_TX: TPSQTP10SQ; TP10SQ
GPS_VPP: TPSQTP10SQ; TP10SQ
LITHIUM-2: LI-2
LI_3V3: TPSQTP10SQ; TP10SQ
LI_AMP: TPSQTP10SQ; TP10SQ
LI_RST: TPSQTP10SQ; TP10SQ
LI_RX: TPSQTP10SQ; TP10SQ
LI_TX: TPSQTP10SQ; TP10SQ
OA_RST: TPSQTP10SQ; TP10SQ
PINAV-CONNECTOR: HLE-110-02-X-DVHLE-110-X-DV-PE-BA; HLE-110-02-X-DV-PE-BE
R1: 47k; R0805
R2: 0; R0805
U$1: PC104_NO_DIMENSION

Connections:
3V3: C1.1, LITHIUM-2.3.3V, LI_3V3.TP, R1.1, U$1.79 (3V3BUS1)
GND: C1.2, C2.2, C3.2, C4.2, GND.TP, LITHIUM-2.GND, LITHIUM-2.RF_GND1 (RF_GND), LITHIUM-2.RF_GND2 (RF_GND), PINAV-CONNECTOR.P$7 (7), PINAV-CONNECTOR.P$15 (15), R2.2, U$1.61 (GND1), U$1.66 (GND2), U$1.69 (GND3), U$1.73 (GND4), U$1.74 (GND5), U$1.81 (GND6), U$1.82 (GND7), U$1.84 (GND8), U$1.99 (GND9), U$1.100 (GND10)
GPS_PF: GPS_PF.TP, PINAV-CONNECTOR.P$6 (6), U$1.24 (GPS_PF)
GPS_RX: GPS_RX.TP, PINAV-CONNECTOR.P$2 (2), U$1.35 (GPS_RX)
GPS_TX: GPS_TX.TP, PINAV-CONNECTOR.P$1 (1), U$1.33 (GPS_TX)
GPS_VPP: GPS_VPP.TP, PINAV-CONNECTOR.P$5 (5), U$1.23 (GPS_VPP)
LI_RST: LITHIUM-2.RESET (!RESET), LI_RST.TP, R1.2, U$1.27 (LI_RESET)
LI_RX: LITHIUM-2.RX_UART, LI_RX.TP, U$1.29 (LI_RX)
LI_TX: LITHIUM-2.TX_UART, LI_TX.TP, U$1.31 (LI_TX)
MNT1: LITHIUM-2.RF_GND (THERM), LITHIUM-2.THERM1 (THERM), LITHIUM-2.THERM2 (THERM), LITHIUM-2.THERM3 (THERM), LITHIUM-2.THERM4 (THERM), R2.1, U$1.MNT1
OA_RESET: LITHIUM-2.CONFIG1, OA_RST.TP, U$1.47 (LI_OA_RST)
SW3: C2.1, LITHIUM-2.V_AMP1 (V_AMP), LITHIUM-2.V_AMP2 (V_AMP), LI_AMP.TP, U$1.63 (SW3_BAT)
SW9: C3.1, C4.1, GPS_3V3.TP, PINAV-CONNECTOR.P$8 (8), PINAV-CONNECTOR.P$14 (14), U$1.71 (SW9_3V3)

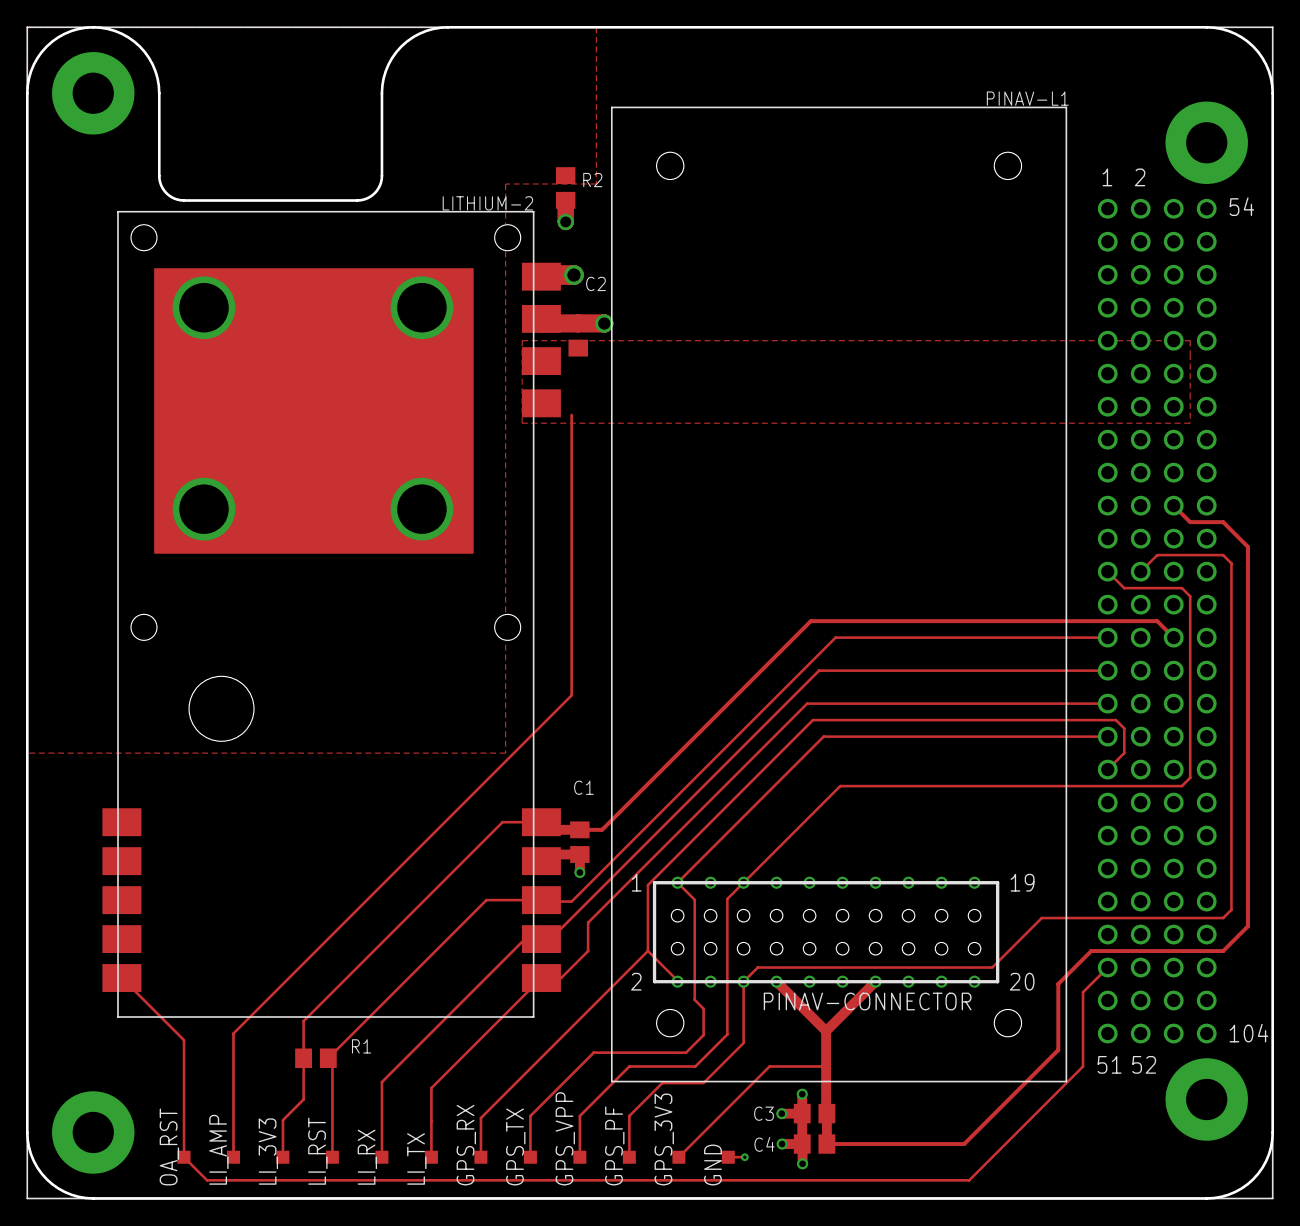
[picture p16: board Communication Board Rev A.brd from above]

Board: 2 copper layers, 95.9 x 90.2 mm, 22 parts (0 on the bottom side), 13 nets.

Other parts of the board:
PINAV-L1: PINAV-L1

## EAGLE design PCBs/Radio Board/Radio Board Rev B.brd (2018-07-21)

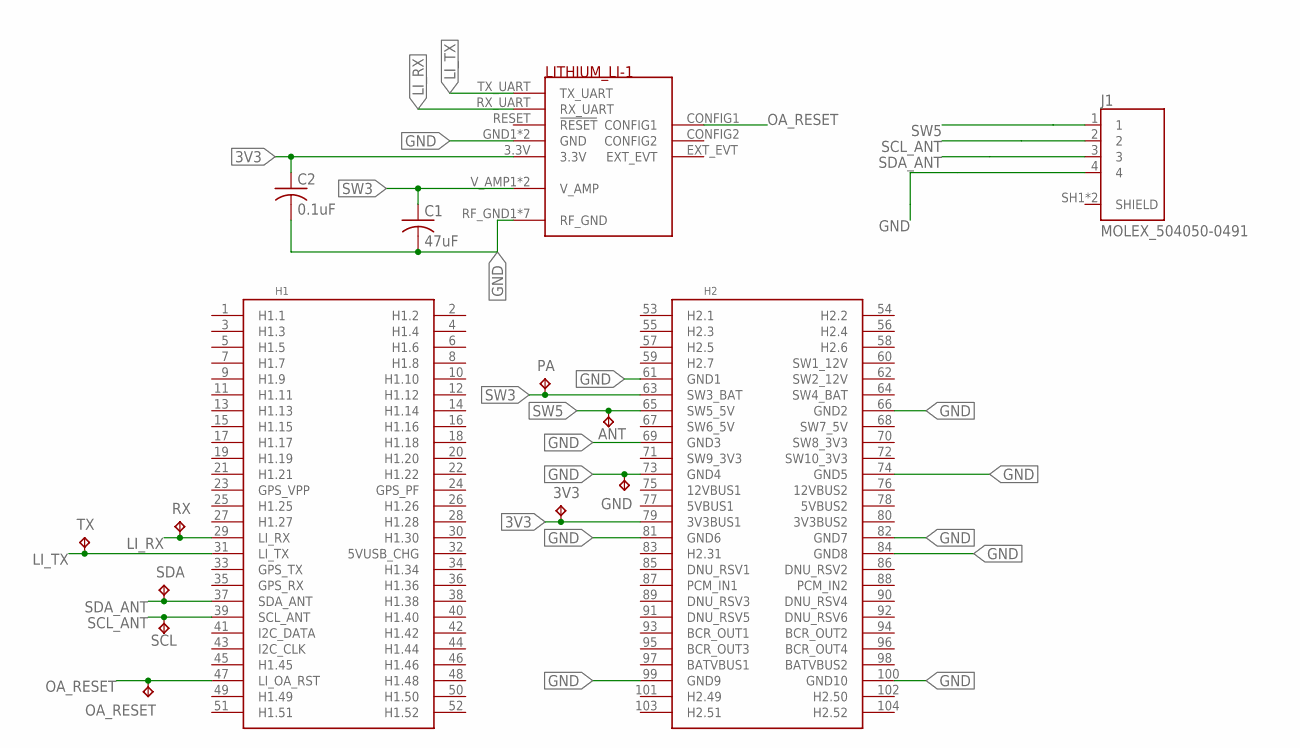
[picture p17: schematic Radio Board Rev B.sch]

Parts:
3V3: TPTP10SQ; TP10SQ
ANT: TPTP10SQ; TP10SQ
C1: 47uF; C0805
C2: 0.1uF; C0805
GND: TPTP10SQ; TP10SQ
J1: MOLEX_504050-0491; MOLEX_5040500491
LI-1: LI-1
OA_RESET: TPTP10SQ; TP10SQ
PA: TPTP10SQ; TP10SQ
RX: TPTP10SQ; TP10SQ
SCL: TPTP10SQ; TP10SQ
SDA: TPTP10SQ; TP10SQ
TX: TPTP10SQ; TP10SQ
U$1: PC104_NO_DIMENSION

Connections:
3V3: 3V3.TP, C2.1, LI-1.3.3V, U$1.79 (3V3BUS1)
GND: C1.2, C2.2, GND.TP, J1.4, LI-1.GND1 (GND), LI-1.GND2 (GND), LI-1.RF_GND1 (RF_GND), LI-1.RF_GND2 (RF_GND), LI-1.RF_GND3 (RF_GND), LI-1.THERM1 (RF_GND), LI-1.THERM2 (RF_GND), LI-1.THERM3 (RF_GND), LI-1.THERM4 (RF_GND), U$1.61 (GND1), U$1.66 (GND2), U$1.69 (GND3), U$1.73 (GND4), U$1.74 (GND5), U$1.81 (GND6), U$1.82 (GND7), U$1.84 (GND8), U$1.99 (GND9), U$1.100 (GND10)
LI_RX: LI-1.RX_UART, RX.TP, U$1.29 (LI_RX)
LI_TX: LI-1.TX_UART, TX.TP, U$1.31 (LI_TX)
OA_RESET: LI-1.CONFIG1, OA_RESET.TP, U$1.47 (LI_OA_RST)
SCL_ANT: J1.2, SCL.TP, U$1.39 (SCL_ANT)
SDA_ANT: J1.3, SDA.TP, U$1.37 (SDA_ANT)
SHIELD: J1.SH1 (SHIELD), J1.SH2 (SHIELD)
SW3: C1.1, LI-1.V_AMP1 (V_AMP), LI-1.V_AMP2 (V_AMP), PA.TP, U$1.63 (SW3_BAT)
SW5: ANT.TP, J1.1, U$1.65 (SW5_5V)

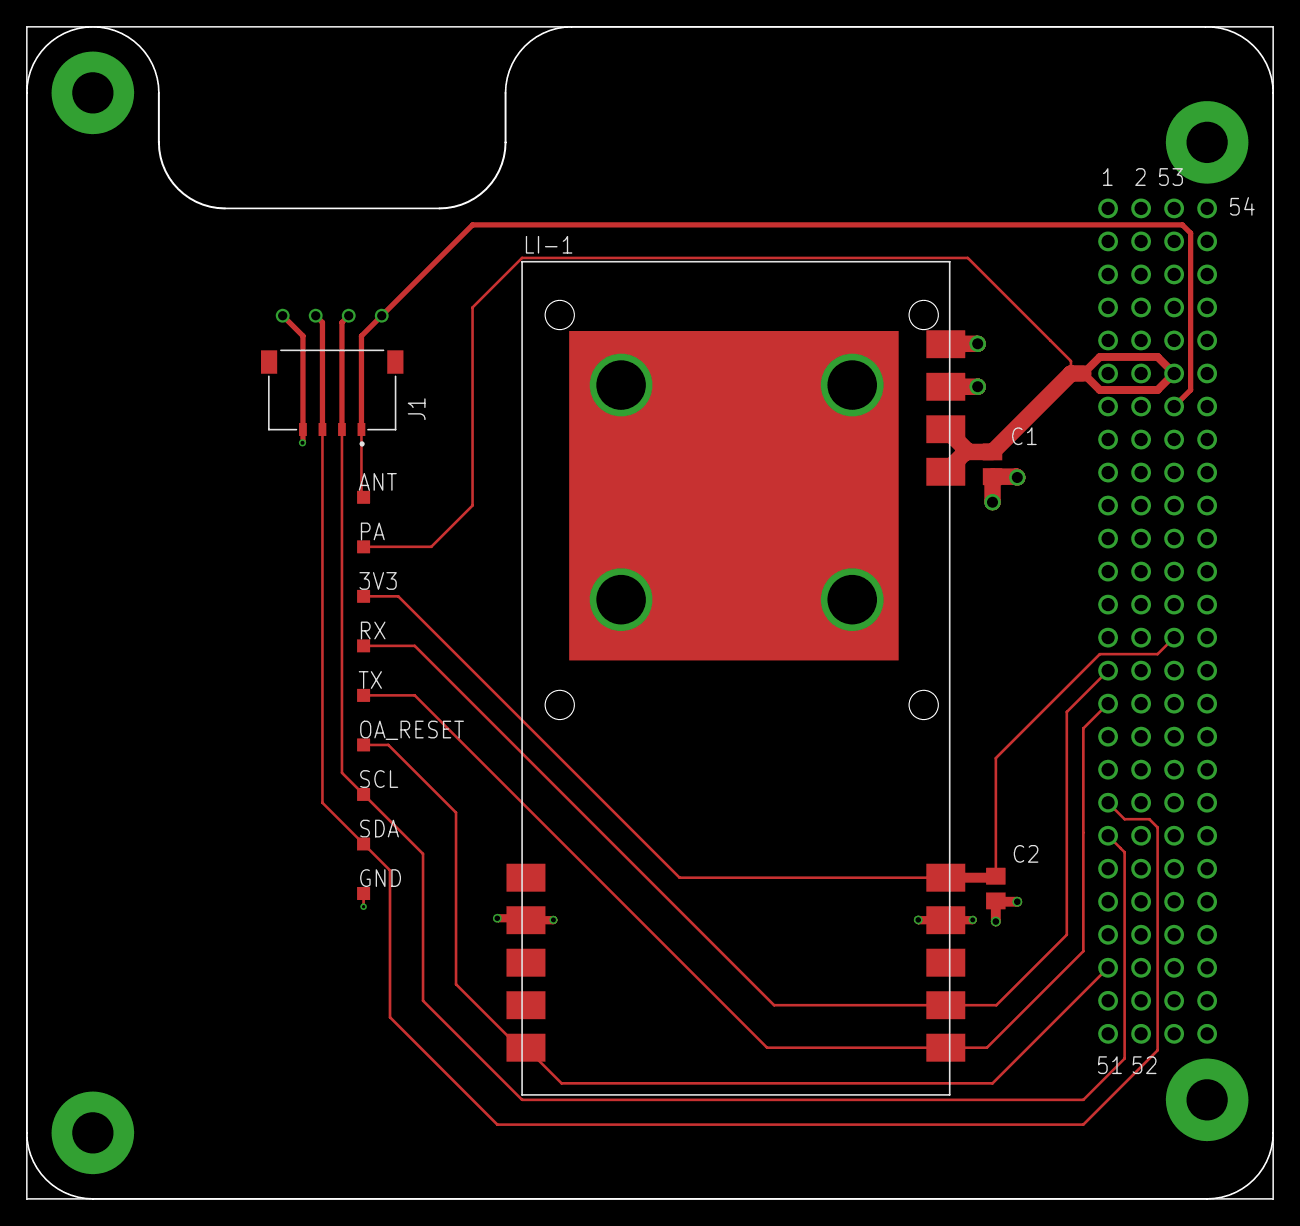
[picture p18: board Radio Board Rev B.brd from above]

Board: 2 copper layers, 95.9 x 90.2 mm, 14 parts (0 on the bottom side), 10 nets.

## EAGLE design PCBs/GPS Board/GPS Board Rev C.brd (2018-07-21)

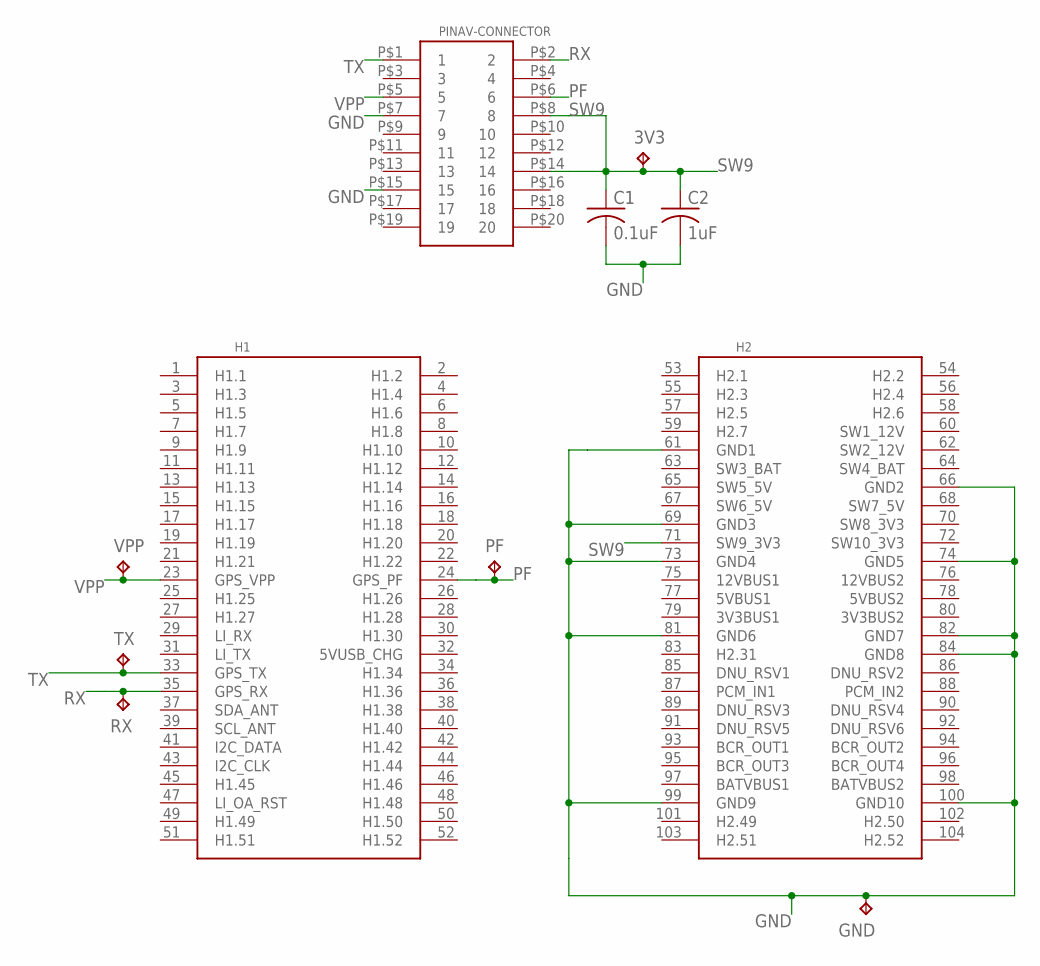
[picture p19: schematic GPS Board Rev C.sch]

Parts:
3V3: TPTP10SQ; TP10SQ
C1: 0.1uF; C0805
C2: 1uF; C0805
GND: TPTP10SQ; TP10SQ
PF: TPTP10SQ; TP10SQ
PINAV-CONNECTOR: HLE-110-02-X-DVHLE-110-X-DV-PE-BA; HLE-110-02-X-DV-PE-BE
RX: TPTP10SQ; TP10SQ
TX: TPTP10SQ; TP10SQ
U$2: PC104_NO_DIMENSION
VPP: TPTP10SQ; TP10SQ

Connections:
GND: C1.2, C2.2, GND.TP, PINAV-CONNECTOR.P$7 (7), PINAV-CONNECTOR.P$15 (15), U$2.61 (GND1), U$2.66 (GND2), U$2.69 (GND3), U$2.73 (GND4), U$2.74 (GND5), U$2.81 (GND6), U$2.82 (GND7), U$2.84 (GND8), U$2.99 (GND9), U$2.100 (GND10)
PF: PF.TP, PINAV-CONNECTOR.P$6 (6), U$2.24 (GPS_PF)
RX: PINAV-CONNECTOR.P$2 (2), RX.TP, U$2.35 (GPS_RX)
SW9: 3V3.TP, C1.1, C2.1, PINAV-CONNECTOR.P$8 (8), PINAV-CONNECTOR.P$14 (14), U$2.71 (SW9_3V3)
TX: PINAV-CONNECTOR.P$1 (1), TX.TP, U$2.33 (GPS_TX)
VPP: PINAV-CONNECTOR.P$5 (5), U$2.23 (GPS_VPP), VPP.TP

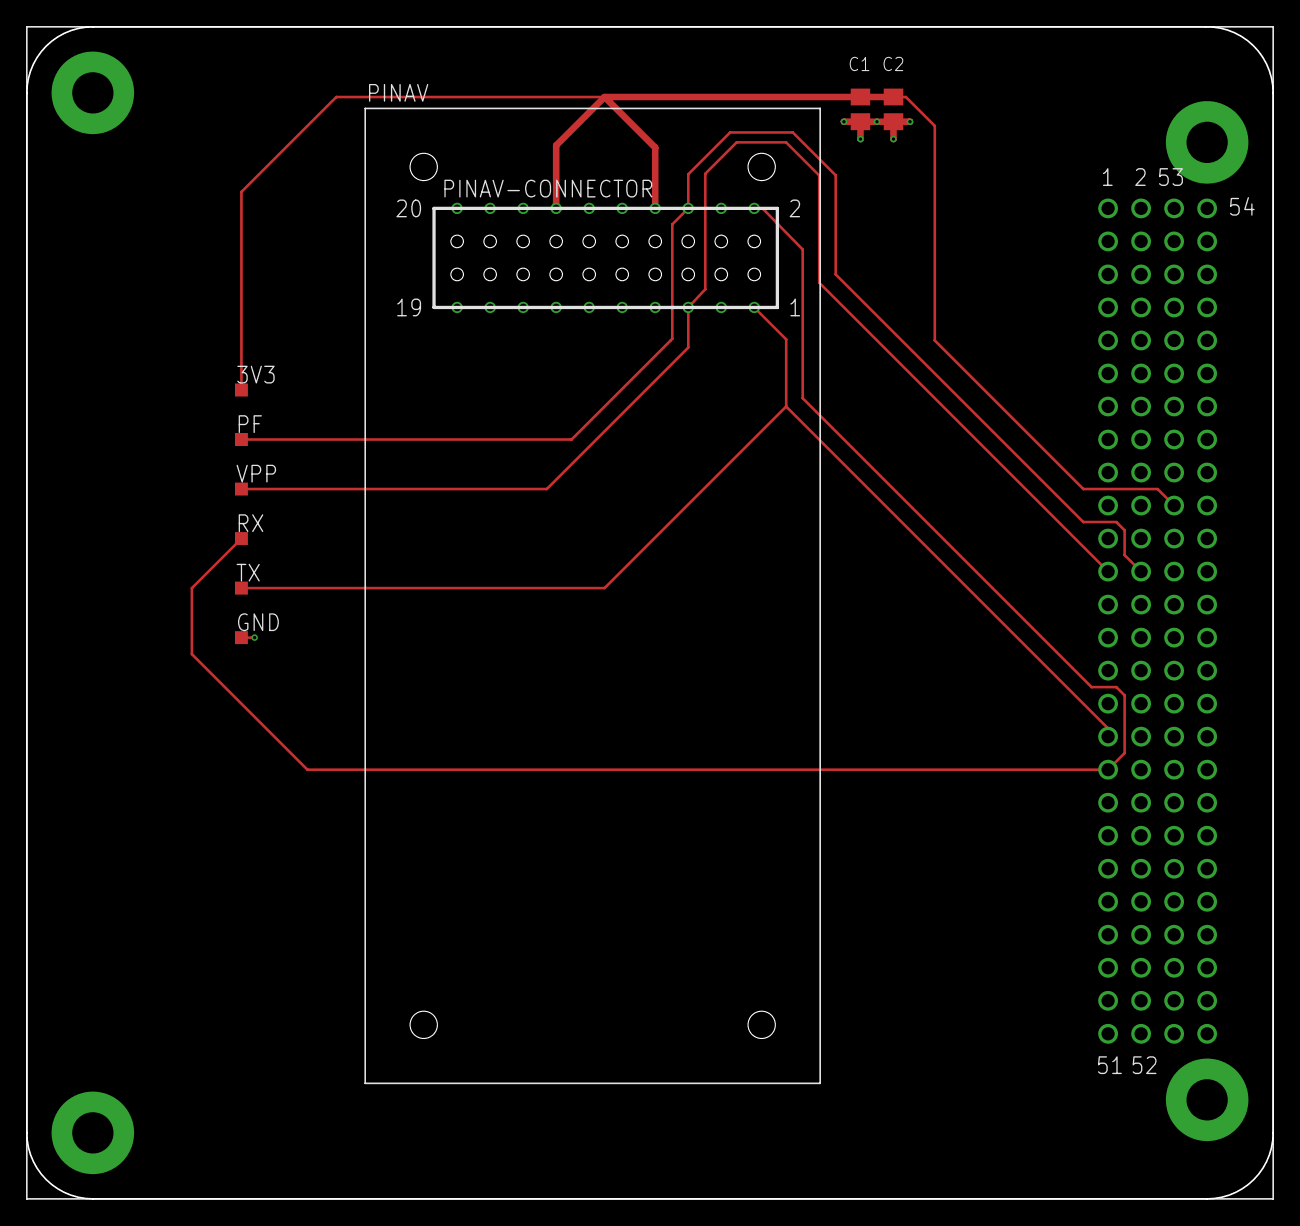
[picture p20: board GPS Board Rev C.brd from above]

Board: 2 copper layers, 95.9 x 90.2 mm, 11 parts (0 on the bottom side), 6 nets.

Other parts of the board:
PINAV: PINAV-L1

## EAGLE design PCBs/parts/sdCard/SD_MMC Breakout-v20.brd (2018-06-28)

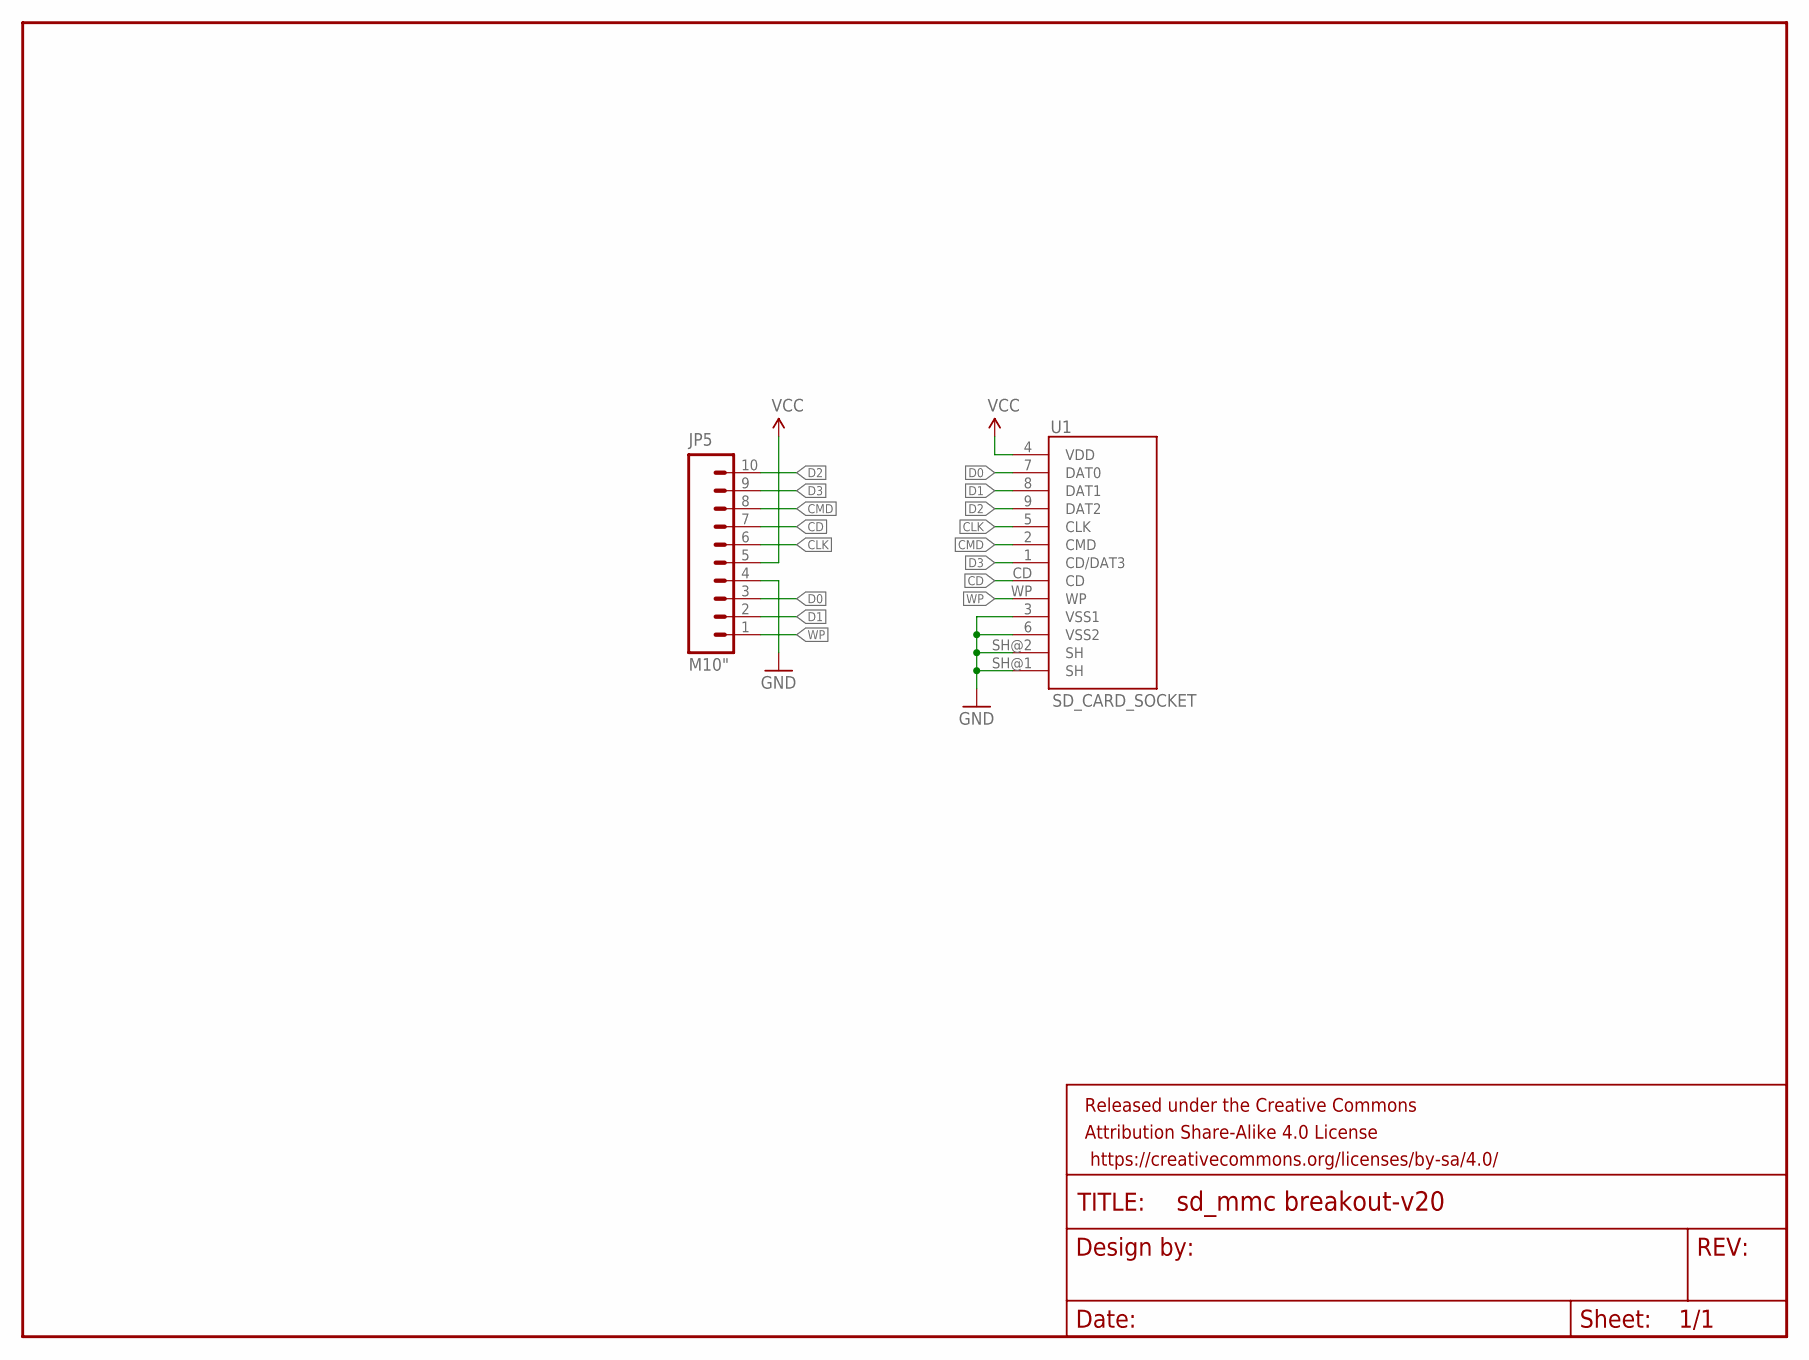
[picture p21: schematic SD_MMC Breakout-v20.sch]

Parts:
FRAME1: FRAME-LETTER; CREATIVE_COMMONS
JP5: M10"; 1X10
U1: SD_CARD_SOCKET; SD_1:1

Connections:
CD: JP5.7, U1.CD
CLK: JP5.6, U1.5 (CLK)
CMD: JP5.8, U1.2 (CMD)
D0: JP5.3, U1.7 (DAT0)
D1: JP5.2, U1.8 (DAT1)
D2: JP5.10, U1.9 (DAT2)
D3: JP5.9, U1.1 (CD/DAT3)
GND: JP5.4, U1.3 (VSS1), U1.6 (VSS2), U1.SH@1 (SH), U1.SH@2 (SH)
VCC: JP5.5, U1.4 (VDD)
WP: JP5.1, U1.WP

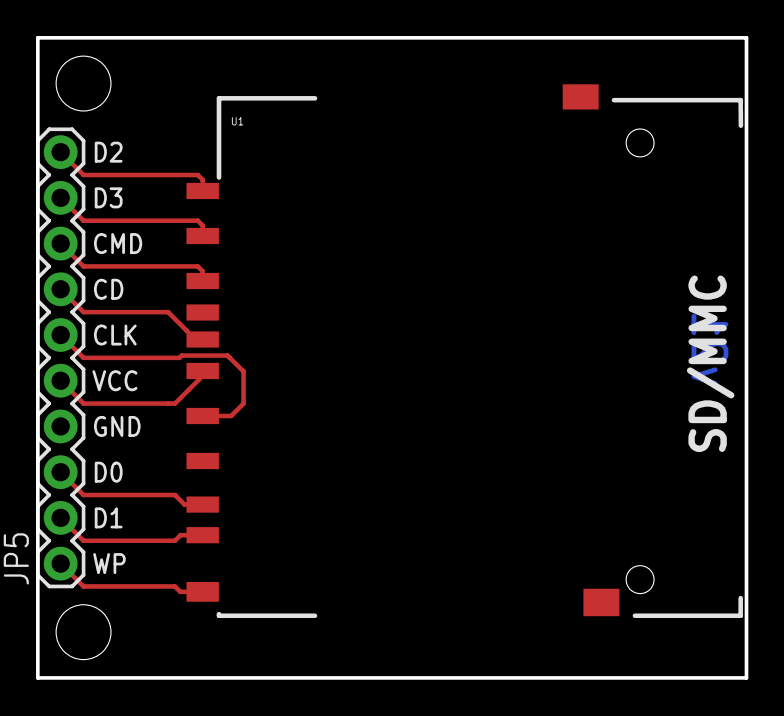
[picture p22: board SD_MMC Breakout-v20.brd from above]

Board: 2 copper layers, 39.4 x 35.6 mm, 5 parts (0 on the bottom side), 10 nets.

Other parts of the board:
U$4, U$5: STAND-OFF-TIGHT

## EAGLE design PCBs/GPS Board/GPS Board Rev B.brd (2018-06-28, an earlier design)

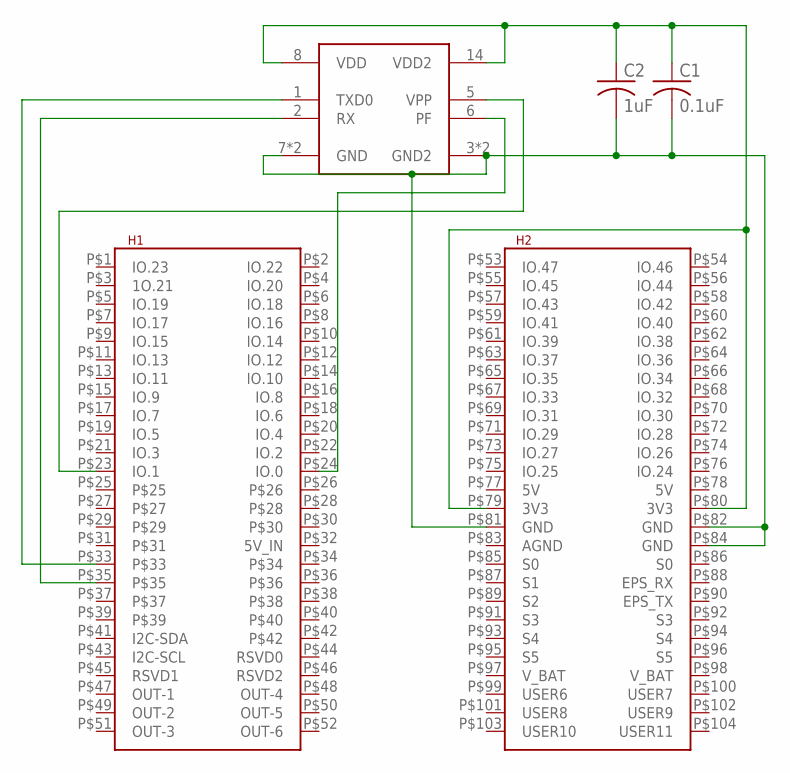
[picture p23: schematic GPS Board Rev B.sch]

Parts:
C1: 0.1uF; C0603
C2: 1uF; C0603
U$1: PINAVL1; PINAV-L1
U$2: PC104

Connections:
GND: C1.2, C2.2, U$1.3 (GND2), U$1.7 (GND), U$1.15 (GND2), U$1.16 (GND), U$2.P$81 (GND), U$2.P$82 (GND), U$2.P$84 (GND)
unnamed: U$1.5 (VPP), U$2.P$23 (IO.1)
unnamed: U$1.6 (PF), U$2.P$24 (IO.0)
unnamed: C1.1, C2.1, U$1.8 (VDD), U$1.14 (VDD2), U$2.P$79 (3V3), U$2.P$80 (3V3)
unnamed: U$1.1 (TXD0), U$2.P$33
unnamed: U$1.2 (RX), U$2.P$35


Board: 2 copper layers, 4 parts (0 on the bottom side), 6 nets.

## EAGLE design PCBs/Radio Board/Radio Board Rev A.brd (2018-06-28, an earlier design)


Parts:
U$1: LITHIUM; LI-1
U$2: PC104
U$3: MSP430F5438A; PZ100
U$4: RFM69HCWSMT; RFM69HCW-SMT
U$5: SD_SHIELD

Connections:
3.3V_BUS: U$1.3.3V, U$2.P$79 (H2_P27), U$2.P$80 (H2_P28), U$3.11, U$4.3V3, U$5.VCC
5V_BUS: U$2.P$77 (H2_P25), U$2.P$78 (H2_P26)
5V_USB_CHRGE: U$2.P$32 (H1_P32)
12V_BUS: U$2.P$75 (H2_P23), U$2.P$76 (H2_P24)
15: U$3.15
16: U$3.16
37: U$3.37
38: U$3.38
62: U$3.62
63: U$3.63
64: U$3.64
87: U$3.87
88: U$3.88
BATTV_BUS: U$2.P$97 (H2_P45), U$2.P$98 (H2_P46)
BCR_OUT: U$2.P$93 (H2_P41), U$2.P$94 (H2_P42), U$2.P$95 (H2_P43), U$2.P$96 (H2_P44)
GND: U$1.GND1 (GND), U$1.GND2 (GND), U$2.P$61 (H2_P9), U$2.P$66 (H2_P14), U$2.P$69 (H2_P17), U$2.P$73 (H2_P21), U$2.P$74 (H2_P22), U$2.P$81 (H2_P29), U$2.P$82 (H2_P30), U$2.P$84 (H2_P32), U$2.P$99 (H2_P47), U$2.P$100 (H2_P48), U$3.12, U$4.GND, U$4.GND@1 (GND), U$4.GND@2 (GND), U$5.GND
LITHIUM_RX_AURT: U$3.39
LITHIUM_RX_UART: U$1.RX_UART
LITHIUM_TX_UART: U$1.TX_UART, U$3.40
MISO: U$3.54, U$3.70, U$4.MISO, U$5.D0
MOSI: U$3.53, U$3.69, U$4.MOSI, U$5.DI
PCM_IN: U$2.P$87 (H2_P35), U$2.P$88 (H2_P36)
RFM_COMPONENT_ANT: U$4.ANT
SCL: U$2.P$43 (H1_P43), U$3.35
SDA: U$2.P$41 (H1_P41), U$3.34
SPI_CLK: U$3.68, U$4.SCK, U$5.SCK
SS1: U$3.71, U$4.NSS
SS2: U$3.52, U$5.CS
SW1: U$2.P$60 (H2_P8)
SW2: U$2.P$62 (H2_P10)
SW3: U$2.P$63 (H2_P11)
SW4: U$2.P$64 (H2_P12)
SW5: U$2.P$65 (H2_P13)
SW6: U$2.P$67 (H2_P15)
SW7: U$2.P$68 (H2_P16)
SW8: U$2.P$70 (H2_P18)
SW9: U$2.P$71 (H2_P19)
SW10: U$2.P$72 (H2_P20)


Board: 2 copper layers, 160.0 x 100.0 mm, 5 parts (0 on the bottom side), 15 nets.

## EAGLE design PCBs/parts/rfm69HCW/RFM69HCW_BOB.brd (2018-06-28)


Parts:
C1: 10uF; 1210
C2: 0.1uF; 0603-CAP
FID1, FID2: FIDUCIAL1X2; FIDUCIAL-1X2
FRAME1: FRAME-LETTER; CREATIVE_COMMONS
JP1: M021X02_NO_SILK; 1X02_NO_SILK
JP2, JP4: M05_ROUNDONLY_NOSILK; 1X05_ROUNDONLY_NOSILK
JP3: M01SMDNS; 1X01NS
JP5: ANTENNA; 1X03_ROUND_ONLY_NO_SILK
LOGO1: SFE_LOGO_NAME.1_INCH; SFE_LOGO_NAME_.1
LOGO2: OSHW-LOGOS; OSHW-LOGO-S
U1: RFM69HCW; RFM69HCW-XXXS2

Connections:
3.3V: C1.1, C2.1, JP1.1, U1.13 (3.3V)
ANT: JP5.2, U1.9 (ANT)
DIO0: JP3.1, U1.14 (DIO0)
DIO1: JP4.1, U1.15 (DIO1)
DIO2: JP4.2, U1.16 (DIO2)
DIO3: JP4.3, U1.11 (DIO3)
DIO4: JP4.4, U1.12 (DIO4)
DIO5: JP4.5, U1.7 (DIO5)
GND: C1.2, C2.2, JP1.2, JP5.1, JP5.3, U1.1 (GND), U1.8 (GND), U1.10 (GND)
MISO: JP2.1, U1.2 (MISO)
MOSI: JP2.2, U1.3 (MOSI)
NSS: JP2.4, U1.5 (NSS)
RESET: JP2.5, U1.6 (RESET)
SCK: JP2.3, U1.4 (SCK)

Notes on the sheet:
M Grusin
1.0
Note: Mark board with frequency of installed module
Antenna length (1/4 wave) 915MHz: 3.07" = 78mm 434MHz: 6.47" = 164mm



Board: 2 copper layers, 27.9 x 20.3 mm, 13 parts (2 on the bottom side), 14 nets.

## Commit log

2018-06-28 Add PCBs and working revs
    [GPS Board Rev A.brd, GPS Board Rev A.sch, GPS Board Rev B.brd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]
2018-07-03 Added bypass caps to radio
    [Radio Board Rev B.brd, Radio Board Rev B.sch]
2018-07-03 Changed GPS power source to an EPS PDM, tweaked trace width
    [GPS Board Rev C.brd, GPS Board Rev C.sch]
2018-07-03 Updated pin-mappings, added SD card
    [Motherboard Rev B.sch]
2018-07-03 Changed SD card connector
    [Motherboard Rev B.sch]
2018-07-03 Add interfacing references
    [Component Interfaces.ods, PC104 Pin Assignments.ods]
2018-07-03 Add SOIC 8 AD590KRZ part
    [Eagle.sch]
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2018-07-03 Fix schematic origin
2018-07-03 Add temp sensors to GPS and Radio boards
    [GPS Board Rev C.brd, GPS Board Rev C.sch, Motherboard Rev B.sch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]
2018-07-04 Temp sensor pins
    [PC104 Pin Assignments.ods]
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2018-07-04 Updated mobo, began mobo layout
    [Motherboard Rev B.brd, Motherboard Rev B.sch]
2018-07-05 Corrected IMU pinout
    [Motherboard Rev B.sch]
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2018-07-05 Fixed temp sens pin error
    [PC104 Pin Assignments.ods]
2018-07-05 First working draft... still missing sensing and JTAG elements
    [Motherboard Rev B.brd, Motherboard Rev B.sch]
2018-07-05 Rotated GPS, bumped cap to 10uF
    [GPS Board Rev C.brd, GPS Board Rev C.sch]
2018-07-06 Changed Li Tx/Rx pins
    [PC104 Pin Assignments.ods, Radio Board Rev B.brd, Radio Board Rev B.sch]
2018-07-06 Remove temp sensors, move radio and uC to 3V3 bus
    [PC104 Pin Assignments.ods]
2018-07-07 Remove temp sensor, tweak trace width
    [Radio Board Rev B.brd, Radio Board Rev B.sch]
2018-07-07 Remove temp sensors, tweak trace width
    [GPS Board Rev C.brd, GPS Board Rev C.sch]
2018-07-07 Replace components with 0805s
    [GPS Board Rev C.brd, GPS Board Rev C.sch]
2018-07-07 Make GPS board pass ERC and DRC
    [GPS Board Rev C.brd, GPS Board Rev C.sch]
2018-07-09 Added Lithium OA system reset
    [PC104 Pin Assignments.ods, Radio Board Rev B.brd, Radio Board Rev B.sch]
2018-07-10 Add combined Radio/GPS board, if needed
    [Radio and GPS Rev A.brd, Radio and GPS Rev A.sch]
2018-07-10 Update radio board to use new library
    [Radio Board Rev B.brd, Radio Board Rev B.sch]
2018-07-10 Add MicroSD, Hirose, and TPS22942 parts
    [Eagle.sch]
2018-07-11 Use different PC104 footprints for each board
    [Radio Board Rev B.brd, Radio Board Rev B.sch]
2018-07-11 Update GPS board to use new library
    [GPS Board Rev C.brd, GPS Board Rev C.sch]
2018-07-11 Missed a connection
    [Radio Board Rev B.brd]
2018-07-11 Fix thermal/ground connection of radio
    [Radio Board Rev B.brd, Radio Board Rev B.sch]
2018-07-11 Replace motherboard footprint with new library
    [Motherboard Rev B.brd, Motherboard Rev B.sch]
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2018-07-12 Use common PC104 footprint with dimensions set per board
    [GPS Board Rev C.brd, GPS Board Rev C.sch, Motherboard Rev B.brd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]
2018-07-12 Add hardware interfaces for radio, GPS
    [Component Interfaces.ods]
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2018-07-13 Add TI REF3330 voltage reference part
    [DBZ0003A.stp, Eagle.sch]
2018-07-13 Added DF11-4DP connector part
    [Eagle.sch]
2018-07-13 Add Molex connector and connector bypass to radio board
    [Radio Board Rev B.brd, Radio Board Rev B.sch]
2018-07-13 Correct Molex connection
    [Radio Board Rev B.brd]
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2018-07-14 Rearrange pins to keep traces only on topside
    [GPS Board Rev C.brd]
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2018-07-18 Update piNAV connector to PE-BE model
    [GPS Board Rev C.brd, GPS Board Rev C.sch]
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2018-07-19 Split I2C and SPI buses
    [Motherboard Rev B.brd, Motherboard Rev B.sch, PC104 Pin Assignments.ods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]
2018-07-19 Add SD card detect to 7.2
    [MSP430 Pin Assignments.ods, Motherboard Rev B.brd, Motherboard Rev B.sch]
2018-07-19 Fix trace collision
    [Radio Board Rev B.brd]
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2018-07-20 Replace SD connector with a model hand-solderable
    [Motherboard Rev B.brd, Motherboard Rev B.sch]
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2018-07-20 Use 5-pin Pico-Lock for sensor harness
    [Motherboard Rev B.brd, Motherboard Rev B.sch]
2018-07-20 Changed opamps used in sensing circuits
    [Eagle.sch, Motherboard Rev B.brd, Motherboard Rev B.sch]
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2018-07-21 Improve decoupling, ground impedance, silkscreens
    [GPS Board Rev C.brd, GPS Board Rev C.sch, Radio Board Rev B.brd]
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2018-07-21 Add testpads, improve bypassing, update routing
    [Radio and GPS Rev A.brd, Radio and GPS Rev A.sch]
2018-07-22 Add xtals, antenna harness, finish most wiring
    [Motherboard Rev B.brd, Motherboard Rev B.sch]
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2018-07-23 Move SD, make room for RBF
    [Motherboard Rev B.brd]
2018-07-24 Add external 5V charging jack
    [Motherboard Rev B.brd, Motherboard Rev B.sch]
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2018-07-25 Replace radio with Li-2 footprint
    [Radio and GPS Rev A.brd, Radio and GPS Rev A.sch]
2018-07-25 Swap JTAG UART and piNAV comm channels
    [MSP430 Pin Assignments.ods, Motherboard Rev B.brd, Motherboard Rev B.sch]
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2018-07-25 Add external UART connector
    [Motherboard Rev B.brd, Motherboard Rev B.sch]
2018-07-26 Shrink pads to not short RBF mount
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2018-07-26 Add RBF mount, replace strain gauge with temp sensor, clean up crossed traces, dimension PCB to accomodate wiring
    [Motherboard Rev B.brd, Motherboard Rev B.sch]
2018-07-26 Update sidewall temp pin assignments
    [MSP430 Pin Assignments.ods]
2018-07-26 Add Antenna and update IMU
    [Component Interfaces.ods]
2018-07-26 Remove antenna I2C pins from bus
    [PC104 Pin Assignments.ods]
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2018-07-27 Rework layout for tighter traces
    [Motherboard Rev B.brd, Motherboard Rev B.sch]
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2018-07-28 Remove outline cuts for inhibits
    [Motherboard Rev B.brd]
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2018-08-01 Add rev info to silkscreen
    [Radio and GPS Rev A.brd]
2018-08-01 Add test pads, RBF->DF13 wiring, update power distribution, breakout extra I/O pins
    [Motherboard Rev B.brd, Motherboard Rev B.sch]
2018-08-01 Update silkscreen with VT logo
    [Radio and GPS Rev A.brd]
2018-08-01 Add NC pin from RBF
    [Motherboard Rev B.brd, Motherboard Rev B.sch]
2018-08-02 Add Lithium reset pin
    [Motherboard Rev B.brd, Motherboard Rev B.sch, PC104 Pin Assignments.ods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]
2018-08-02 Add pin numbers to bottom silkscreen
    [Radio and GPS Rev A.brd, Radio and GPS Rev A.sch]
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2018-08-02 Add Lithium Reset, GPS PF and VPP
    [MSP430 Pin Assignments.ods]
2018-08-02 Rev B final take 1
    [Motherboard Rev B.brd, Motherboard Rev B.sch]
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2018-08-02 Thermally couple radio to chassis
    [Communication Board Rev A.brd, Communication Board Rev A.sch]
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2018-08-03 Correct milling and pads for elongated pins
2018-08-03 Replace hatching with outline for RBF pin
2018-08-03 Use only 8mil traces
    [Communication Board Rev A.brd]
2018-08-04 Create comm parts list
    [Communication Board Rev A.brd, Communication Board Rev A.sch]
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2018-10-17 Mobo Rev C Initial Commit
    [Motherboard Rev C.brd, Motherboard Rev C.sch]

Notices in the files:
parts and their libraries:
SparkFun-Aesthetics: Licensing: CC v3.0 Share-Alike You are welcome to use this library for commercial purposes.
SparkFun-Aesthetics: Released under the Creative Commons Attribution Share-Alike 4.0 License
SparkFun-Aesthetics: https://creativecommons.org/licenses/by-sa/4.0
